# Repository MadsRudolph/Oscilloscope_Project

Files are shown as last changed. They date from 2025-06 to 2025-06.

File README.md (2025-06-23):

# ⚡ Oscilloscope & Signal Generator — DTU 30082 Project

Welcome to the **Oscilloscope_Project**, developed for the DTU course **30082 – Projektarbejde i Digitalteknik**.  
This full-stack embedded system connects a **Basys 2 FPGA** signal generator, an **ATmega2560 oscilloscope**, and a **LabVIEW GUI**.  
It visualizes analog signals in real time and allows waveform control through a robust UART/SPI interface.

📄 **[Project Report (PDF)](docs/Oscilloscope_Project_Rapport.pdf)**

---

## 📂 Project Structure

```
Oscilloscope_Project/
├── Microcontroller/           # PlatformIO-based ATmega2560 codebase
├── fpga/                      # VHDL projects for signal generation
├── docs/                      # Technical documentation and filter analysis
├── README.md
└── .gitignore
```

---

## 🎯 Project Goal

Design and implement a digital oscilloscope system that:
- Samples analog waveforms with an ATmega2560
- Sends sampled data to a LabVIEW GUI over UART
- Receives waveform control commands via UART (shape, freq, amp)
- Forwards these settings to an FPGA-based signal generator via SPI
- Generates analog output through PWM and active low-pass filtering

---

## 🧰 Technologies Used

| Platform | Tech | Purpose |
|---|---|---|
| ATmega2560 | C / PlatformIO | UART, ADC, SPI, Interrupts |
| FPGA (Basys 2) | VHDL (Xilinx ISE 14.7) | PWM waveform generation via SPI input |
| PC (Windows) | LabVIEW 2014 + NI-VISA | GUI and protocol management |
| Docs | KiCad / LTspice / Maple  | Active filter design + verification |

---

## 📡 Communication Protocols

### UART (MCU ↔ LabVIEW)
- **Baudrate:** `115200`, 8N1
- **Packet Format:**
  ```
  [0x55, 0xAA] + Length (2B) + Type (1B) + Data + Checksum (2B)
  ```
- **Types:**
  - `0x01` — Generator BTN pressed (with SW value)
  - `0x02` — Oscilloscope settings (sample rate, record length)
  - `0x03` — Start Bode plot
  - `0x04` — Trigger SPI stress test

### SPI (MCU → FPGA)
- 4-byte command packets:
  ```
  [0x55][ADDR][DATA][CHKSUM]
  ADDR: 1 = Amplitude, 2 = Frequency, 3 = Shape
  CHKSUM: ADDR ^ 0x55 ^ DATA
  ```

---

## 🔬 Subsystems

### 🟨 Microcontroller (ATmega2560)
- **ADC:** Timer1-triggered, 8-bit resolution (0–3.3V range)
- **UART0:** Debug output
- **UART1:** LabVIEW interface with interrupt-driven RX
- **SPI Master:** Sends waveform configuration to FPGA
- **Double/triple buffer** system for uninterrupted sampling
- **Stress test logic:** Transmits 10,000+ SPI packets after reset

### 🟦 FPGA (Basys 2)
- **PWM Generator:** Look-up tables drive pulse width per shape
- **SPI Slave:** Bit-shift protocol with byte-level sync and XOR validation
- **Waveform Types:** Constant, Square, Sawtooth, Triangle
- **Low-pass filter:** External 2nd–4th order analog smoothing stage

### 🟥 LabVIEW GUI
- **Tabs:** Generator, Oscilloscope, Bode Plot
- **Live Display:** ADC waveform and waveform config feedback
- **User Input:** Shape, amplitude, frequency, sample rate, record length
- **Checksums:** Supports ZERO16, LRC8, CRC16-CCITT
- **Simulator:** Emulate communication without hardware

---

## 🔍 Filter Design

- Designed using **KiCad** and validated in **LTspice**
- Active filters reduce PWM ripple for sine/sawtooth fidelity
- Mathematical modeling and transfer function analysis via **Maple**

### 📈 Output vs Filtered Waveform

The following scope capture shows both the raw PWM signal (red) and the filtered analog output (blue), confirming the effectiveness of the low-pass filter design:

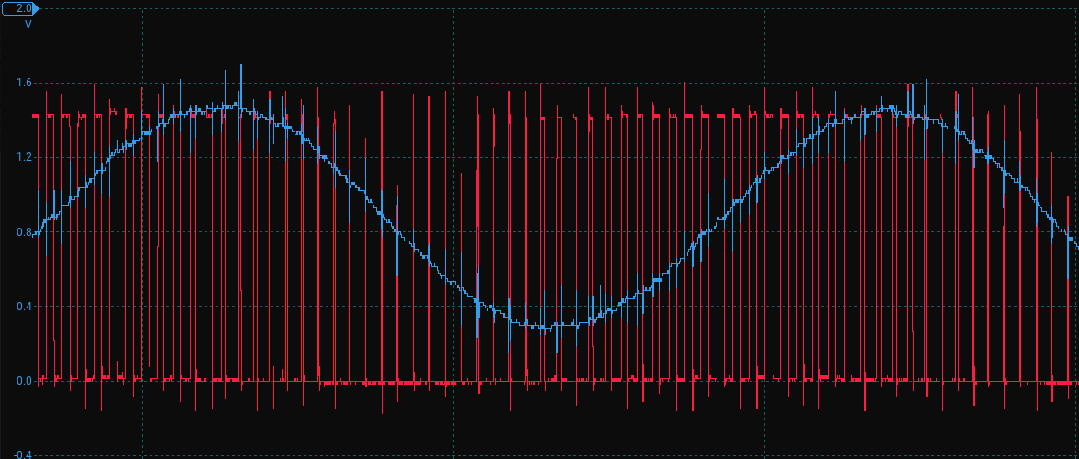
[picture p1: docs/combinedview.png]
Filtered PWM Output


---

## ⚠️ Known Limitations

- ❌ **User cannot freely adjust sample rate**  
  Sample rate is internally derived based on selected record length for optimal performance and continuous sampling.  
  Manual control of the sample rate is not supported in the final version, though it was implemented in earlier iterations.
  
- ✅ **Triangle waveform added**  
  Not part of original spec, added as an extra signal type.

---

## ✅ Features Implemented

- [x] Timer-driven ADC sampling (up to 10,000 sps)
- [x] UART parser with sync header, length, type, and checksum
- [x] SPI communication with custom byte-protocol and integrity checks
- [x] Real-time waveform generation: Constant, Square, Sawtooth, Triangle
- [x] GUI feedback and control via LabVIEW
- [x] External analog filtering tuned to PWM frequency
- [x] SPI stress test system (10k packets + FPGA reset)
- [x] Robust double-buffer system for uninterrupted signal capture

---

## 👥 Authors

**Embedded C (MCU, UART, SPI, ADC):**  
- Mads Rudolph  
- Sigurd Hestbech Christiansen  

**FPGA Design (PWM, LUTs, SPI Slave):**  
- Jonas Jensen  
- Andreas Jacobsen  
- Joakim Butenko

> All members contributed to testing, integration, and review across subsystems.

---

## 🔐 License

This project was created for the **DTU 30082 course** and is released for **educational, non-commercial use only**.

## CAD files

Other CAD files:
fpga/SPI_Test/isim/ProtokolBlok_isim_beh.exe.sim/work/ProtokolBlok_isim_beh.exe_main.nt64.obj
fpga/SPI_Test/isim/TB_TOP34444_isim_beh.exe.sim/work/TB_TOP34444_isim_beh.exe_main.nt64.obj
fpga/SignalGenerator/isim/FULL_BENCH_isim_beh.exe.sim/work/FULL_BENCH_isim_beh.exe_main.nt64.obj
fpga/SignalGenerator/isim/FULL_BENCH_isim_beh.exe.sim/work/a_3343343606_3212880686.nt64.obj
fpga/SignalGenerator/isim/FULL_BENCH_isim_beh.exe.sim/xilinxcorelib/a_2347390556_0543512595.nt64.obj
fpga/SignalGenerator/isim/precompiled.exe.sim/ieee/p_3564397177.nt64.obj
fpga/SignalGenerator/isim/precompiled.exe.sim/std/textio.nt64.obj
fpga/SPI_Test/isim/TB_TOP34444_isim_beh.exe.sim/work/a_4002409220_3212880686.nt64.obj
fpga/SignalGenerator/isim/FULL_BENCH_isim_beh.exe.sim/work/a_3580701064_3212880686.nt64.obj
fpga/SignalGenerator/isim/FULL_BENCH_isim_beh.exe.sim/xilinxcorelib/a_1380994670_2959432447.nt64.obj
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

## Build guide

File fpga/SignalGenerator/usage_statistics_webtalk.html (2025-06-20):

### Device Usage Page (usage_statistics_webtalk.html)

This HTML page displays the device usage statistics that will be sent to Xilinx.

Software Version and Target Device
Product Version: | ISE:14.7 (WebPack) - P.20131013 | Target Family: | Spartan3E
OS Platform: | LIN64 | Target Device: | xc3s100e
Project ID (random number) | 11f8526fd8dd4719a3ffcc0951b1ec72.9B5E89CDEDDC4133BDF7DFD157F22D5D.78 | Target Package: | cp132
Registration ID | 213343244_0_0_270 | Target Speed: | -4
Date Generated | 2025-06-20T10:25:10 | Tool Flow | ISE

User Environment
OS Name | Ubuntu | OS Release | Ubuntu 24.04.1 LTS
CPU Name | AMD Ryzen 7 7435HS | CPU Speed | 3094.104 MHz

Device Usage Statistics
Macro Statistics | Miscellaneous Statistics | Net Statistics | Site Usage

Accumulators=1

12-bit up accumulator=1

Adders/Subtractors=8

16-bit adder=7

9-bit adder=1

Comparators=5

12-bit comparator less=1

16-bit comparator greater=1

16-bit comparator less=1

7-bit comparator lessequal=1

8-bit comparator equal=1

Counters=5

12-bit up counter=2

16-bit up counter=1

2-bit up counter=1

25-bit up counter=1

Decoders=1

1-of-4 decoder=1

FSMs=3 Latches=2

20-bit latch=1

8-bit latch=1

Multiplexers=3

1-bit 4-to-1 multiplexer=1

4-bit 4-to-1 multiplexer=1

8-bit 5-to-1 multiplexer=1

ROMs=1

16x16-bit ROM=1

Registers=77

Flip-Flops=77

Xors=8

1-bit xor2=8

MiscellaneousStatistics

AGG_BONDED_IO=23

AGG_IO=23

AGG_SLICE=235

NUM_4_INPUT_LUT=378

NUM_BONDED_IBUF=6

NUM_BONDED_IOB=17

NUM_BUFGMUX=2

NUM_CYMUX=172

NUM_IOB_FF=1

NUM_LUT_RT=63

NUM_RAMB16=2

NUM_SLICEL=235

NUM_SLICE_FF=165

NUM_SLICE_LATCH=19

NUM_XOR=140

Xilinx Core blk_mem_gen_v7_1, Xilinx CORE Generator 14.1=1

NetStatistics

NumNets_Active=500

NumNets_Gnd=1

NumNets_Vcc=1

NumNodesOfType_Active_BRAMADDR=24

NumNodesOfType_Active_BRAMDUMMY=8

NumNodesOfType_Active_CLKPIN=107

NumNodesOfType_Active_CNTRLPIN=133

NumNodesOfType_Active_DOUBLE=758

NumNodesOfType_Active_DUMMY=1018

NumNodesOfType_Active_DUMMYBANK=28

NumNodesOfType_Active_DUMMYESC=6

NumNodesOfType_Active_GLOBAL=39

NumNodesOfType_Active_HFULLHEX=14

NumNodesOfType_Active_HLONG=1

NumNodesOfType_Active_HUNIHEX=38

NumNodesOfType_Active_INPUT=1228

NumNodesOfType_Active_IOBOUTPUT=6

NumNodesOfType_Active_OMUX=457

NumNodesOfType_Active_OUTPUT=466

NumNodesOfType_Active_PREBXBY=305

NumNodesOfType_Active_VFULLHEX=28

NumNodesOfType_Active_VLONG=10

NumNodesOfType_Active_VUNIHEX=37

NumNodesOfType_Vcc_BRAMDUMMY=2

NumNodesOfType_Vcc_CNTRLPIN=2

NumNodesOfType_Vcc_INPUT=7

NumNodesOfType_Vcc_PREBXBY=4

NumNodesOfType_Vcc_VCCOUT=8

SiteStatistics

IBUF-DIFFM=3

IBUF-DIFFMI=1

IBUF-IOB=1

IOB-DIFFM=7

IOB-DIFFS=8

SLICEL-SLICEM=96

SiteSummary

BUFGMUX=2

BUFGMUX_GCLKMUX=2

BUFGMUX_GCLK_BUFFER=2

IBUF=6

IBUF_INBUF=6

IBUF_PAD=6

IOB=17

IOB_OFF1=1

IOB_OUTBUF=17

IOB_PAD=17

RAMB16=2

RAMB16_RAMB16=2

RAMB16_RAMB16A=2

RAMB16_RAMB16B=2

SLICEL=235

SLICEL_C1VDD=3

SLICEL_C2VDD=11

SLICEL_CYMUXF=89

SLICEL_CYMUXG=83

SLICEL_F=201

SLICEL_F5MUX=19

SLICEL_FFX=95

SLICEL_FFY=89

SLICEL_G=177

SLICEL_GNDF=51

SLICEL_GNDG=38

SLICEL_XORF=71

SLICEL_XORG=69

Configuration Data

BUFGMUX

S=[S_INV:2] [S:0]

BUFGMUX_GCLKMUX

DISABLE_ATTR=[LOW:2]

S=[S_INV:2] [S:0]

IBUF

ICLK1=[ICLK1_INV:0] [ICLK1:1]

SR=[SR:1] [SR_INV:0]

IBUF_IFF1

CK=[CK:1] [CK_INV:0]

IFF1_INIT_ATTR=[INIT0:1]

IFF1_SR_ATTR=[SRLOW:1]

IFFATTRBOX=[ASYNC:1]

LATCH_OR_FF=[FF:1]

SR=[SR:1] [SR_INV:0]

IBUF_INBUF

IFD_DELAY_VALUE=[DLY2:1]

IBUF_PAD

IOATTRBOX=[LVCMOS25:6]

IOB

O1=[O1_INV:1] [O1:16]

OTCLK1=[OTCLK1_INV:0] [OTCLK1:1]

SR=[SR:1] [SR_INV:0]

IOB_OFF1

CK=[CK:1] [CK_INV:0]

D=[D:1] [D_INV:0]

LATCH_OR_FF=[FF:1]

OFF1_INIT_ATTR=[INIT0:1]

OFF1_SR_ATTR=[SRLOW:1]

OFFATTRBOX=[ASYNC:1]

SR=[SR:1] [SR_INV:0]

IOB_OUTBUF

IN=[IN_INV:1] [IN:16]

IOB_PAD

DRIVEATTRBOX=[12:17]

IOATTRBOX=[LVCMOS25:17]

SLEW=[SLOW:17]

RAMB16

CLKA=[CLKA_INV:0] [CLKA:2]

CLKB=[CLKB_INV:0] [CLKB:2]

ENA=[ENA_INV:0] [ENA:2]

ENB=[ENB_INV:0] [ENB:2]

SSRA=[SSRA_INV:0] [SSRA:2]

SSRB=[SSRB_INV:0] [SSRB:2]

WEA=[WEA:2] [WEA_INV:0]

WEB=[WEB:2] [WEB_INV:0]

RAMB16_RAMB16A

CLKA=[CLKA_INV:0] [CLKA:2]

ENA=[ENA_INV:0] [ENA:2]

PORTA_ATTR=[4096X4:2]

SSRA=[SSRA_INV:0] [SSRA:2]

WEA=[WEA:2] [WEA_INV:0]

WRITEMODEA=[WRITE_FIRST:2]

RAMB16_RAMB16B

CLKB=[CLKB_INV:0] [CLKB:2]

ENB=[ENB_INV:0] [ENB:2]

PORTB_ATTR=[4096X4:2]

SSRB=[SSRB_INV:0] [SSRB:2]

WEB=[WEB:2] [WEB_INV:0]

WRITEMODEB=[WRITE_FIRST:2]

SLICEL

BX=[BX_INV:0] [BX:64]

BY=[BY:33] [BY_INV:2]

CE=[CE:41] [CE_INV:0]

CIN=[CIN_INV:0] [CIN:80]

CLK=[CLK:92] [CLK_INV:12]

SR=[SR:91] [SR_INV:0]

SLICEL_CYMUXF

0=[0:89] [0_INV:0]

1=[1_INV:0] [1:89]

SLICEL_CYMUXG

0=[0:83] [0_INV:0]

SLICEL_F5MUX

S0=[S0:19] [S0_INV:0]

SLICEL_FFX

CE=[CE:36] [CE_INV:0]

CK=[CK:84] [CK_INV:11]

D=[D:95] [D_INV:0]

FFX_INIT_ATTR=[INIT0:95]

FFX_SR_ATTR=[SRLOW:95]

LATCH_OR_FF=[FF:84] [LATCH:11]

SR=[SR:84] [SR_INV:0]

SYNC_ATTR=[ASYNC:95]

SLICEL_FFY

CE=[CE:41] [CE_INV:0]

CK=[CK:81] [CK_INV:8]

D=[D:87] [D_INV:2]

FFY_INIT_ATTR=[INIT0:88] [INIT1:1]

FFY_SR_ATTR=[SRLOW:87] [SRHIGH:2]

LATCH_OR_FF=[FF:81] [LATCH:8]

SR=[SR:80] [SR_INV:0]

SYNC_ATTR=[ASYNC:89]

SLICEL_XORF

1=[1_INV:0] [1:71]

Pin Data

BUFGMUX

I0=2

O=2

S=2

BUFGMUX_GCLKMUX

I0=2

OUT=2

S=2

BUFGMUX_GCLK_BUFFER

IN=2

OUT=2

IBUF

I=6

PAD=6

IBUF_IFD_DELAY

IN=1

OUT=1

IBUF_IFF1

CK=1

D=1

Q=1

SR=1

IBUF_INBUF

IN=6

OUT=6

IBUF_PAD

PAD=6

IOB

O1=17

OTCLK1=1

PAD=17

SR=1

IOB_OFF1

CK=1

D=1

Q=1

SR=1

IOB_OUTBUF

IN=17

OUT=17

IOB_PAD

PAD=17

RAMB16

ADDRA10=2

ADDRA11=2

ADDRA12=2

ADDRA13=2

ADDRA2=2

ADDRA3=2

ADDRA4=2

ADDRA5=2

ADDRA6=2

ADDRA7=2

ADDRA8=2

ADDRA9=2

ADDRB10=2

ADDRB11=2

ADDRB12=2

ADDRB13=2

ADDRB2=2

ADDRB3=2

ADDRB4=2

ADDRB5=2

ADDRB6=2

ADDRB7=2

ADDRB8=2

ADDRB9=2

CLKA=2

CLKB=2

DIB0=2

DIB1=2

DIB2=2

DIB3=2

DOA0=2

DOA1=2

DOA2=2

DOA3=2

ENA=2

ENB=2

SSRA=2

SSRB=2

WEA=2

WEB=2

RAMB16_RAMB16

ADDRA=2

ADDRB=2

DIA=2

DIB=2

DOA=2

DOB=2

RAMB16_RAMB16A

ADDRA=2

ADDRA10=2

ADDRA11=2

ADDRA12=2

ADDRA13=2

ADDRA2=2

ADDRA3=2

ADDRA4=2

ADDRA5=2

ADDRA6=2

ADDRA7=2

ADDRA8=2

ADDRA9=2

CLKA=2

DIA=2

DOA=2

DOA0=2

DOA1=2

DOA2=2

DOA3=2

ENA=2

SSRA=2

WEA=2

RAMB16_RAMB16B

ADDRB=2

ADDRB10=2

ADDRB11=2

ADDRB12=2

ADDRB13=2

ADDRB2=2

ADDRB3=2

ADDRB4=2

ADDRB5=2

ADDRB6=2

ADDRB7=2

ADDRB8=2

ADDRB9=2

CLKB=2

DIB=2

DIB0=2

DIB1=2

DIB2=2

DIB3=2

DOB=2

ENB=2

SSRB=2

WEB=2

SLICEL

BX=64

BY=35

CE=41

CIN=80

CLK=104

COUT=83

F1=195

F2=158

F3=105

F4=74

G1=177

G2=142

G3=100

G4=63

SR=91

X=106

XB=2

XQ=95

Y=86

YQ=89

SLICEL_C1VDD

1=3

SLICEL_C2VDD

1=11

SLICEL_CYMUXF

0=89

1=89

OUT=89

S0=89

SLICEL_CYMUXG

0=83

1=83

OUT=83

S0=83

SLICEL_F

A1=195

A2=158

A3=105

A4=74

D=201

SLICEL_F5MUX

F=19

G=19

OUT=19

S0=19

SLICEL_FAND

0=5

1=5

O=5

SLICEL_FFX

CE=36

CK=95

D=95

Q=95

SR=84

SLICEL_FFY

CE=41

CK=89

D=89

Q=89

SR=80

SLICEL_G

A1=177

A2=142

A3=100

A4=63

D=177

SLICEL_GAND

0=9

1=9

O=9

SLICEL_GNDF

0=51

SLICEL_GNDG

0=38

SLICEL_VDDG

1=1

SLICEL_XORF

0=71

1=71

O=71

SLICEL_XORG

0=69

1=69

O=69

Tool Usage

Command Line History

xst -intstyle ise -ifn <ise_file>

xst -intstyle ise -ifn <ise_file>

xst -intstyle ise -ifn <ise_file>

xst -intstyle ise -ifn <ise_file>

xst -intstyle ise -ifn <ise_file>

xst -intstyle ise -ifn <ise_file>

xst -intstyle ise -ifn <ise_file>

xst -intstyle ise -ifn <ise_file>

xst -intstyle ise -ifn <ise_file>

xst -intstyle ise -ifn <ise_file>

xst -intstyle ise -ifn <ise_file>

xst -intstyle ise -ifn <ise_file>

ngdbuild -intstyle ise -dd _ngo -sd <dname> -nt timestamp -uc <ise_file> -p xc3s100e-cp132-4 <fname>.ngc <fname>.ngd

xst -intstyle ise -ifn <ise_file>

ngdbuild -intstyle ise -dd _ngo -sd <dname> -nt timestamp -uc <ise_file> -p xc3s100e-cp132-4 <fname>.ngc <fname>.ngd

xst -intstyle ise -ifn <ise_file>

xst -intstyle ise -ifn <ise_file>

xst -intstyle ise -ifn <ise_file>

xst -intstyle ise -ifn <ise_file>

xst -intstyle ise -ifn <ise_file>

ngdbuild -intstyle ise -dd _ngo -sd <dname> -nt timestamp -uc <ise_file> -p xc3s100e-cp132-4 <fname>.ngc <fname>.ngd

map -intstyle ise -p xc3s100e-cp132-4 -cm area -ir off -pr off -c 100 -o <fname>.ncd <fname>.ngd <fname>.pcf

par -w -intstyle ise -ol high -t 1 <fname>.ncd <fname>.ncd <fname>.pcf

trce -intstyle ise -v 3 -s 4 -n 3 -fastpaths -xml <fname>.twx <fname>.ncd -o <fname>.twr <fname>.pcf

bitgen -intstyle ise -f <fname>.ut <fname>.ncd

xst -intstyle ise -ifn <ise_file>

xst -intstyle ise -ifn <ise_file>

ngdbuild -intstyle ise -dd _ngo -sd <dname> -nt timestamp -uc <ise_file> -p xc3s100e-cp132-4 <fname>.ngc <fname>.ngd

map -intstyle ise -p xc3s100e-cp132-4 -cm area -ir off -pr off -c 100 -o <fname>.ncd <fname>.ngd <fname>.pcf

par -w -intstyle ise -ol high -t 1 <fname>.ncd <fname>.ncd <fname>.pcf

trce -intstyle ise -v 3 -s 4 -n 3 -fastpaths -xml <fname>.twx <fname>.ncd -o <fname>.twr <fname>.pcf

bitgen -intstyle ise -f <fname>.ut <fname>.ncd

xst -intstyle ise -ifn <ise_file>

ngdbuild -intstyle ise -dd _ngo -sd <dname> -nt timestamp -uc <ise_file> -p xc3s100e-cp132-4 <fname>.ngc <fname>.ngd

map -intstyle ise -p xc3s100e-cp132-4 -cm area -ir off -pr off -c 100 -o <fname>.ncd <fname>.ngd <fname>.pcf

par -w -intstyle ise -ol high -t 1 <fname>.ncd <fname>.ncd <fname>.pcf

trce -intstyle ise -v 3 -s 4 -n 3 -fastpaths -xml <fname>.twx <fname>.ncd -o <fname>.twr <fname>.pcf

bitgen -intstyle ise -f <fname>.ut <fname>.ncd

xst -intstyle ise -ifn <ise_file>

ngdbuild -intstyle ise -dd _ngo -sd <dname> -nt timestamp -uc <ise_file> -p xc3s100e-cp132-4 <fname>.ngc <fname>.ngd

map -intstyle ise -p xc3s100e-cp132-4 -cm area -ir off -pr off -c 100 -o <fname>.ncd <fname>.ngd <fname>.pcf

par -w -intstyle ise -ol high -t 1 <fname>.ncd <fname>.ncd <fname>.pcf

trce -intstyle ise -v 3 -s 4 -n 3 -fastpaths -xml <fname>.twx <fname>.ncd -o <fname>.twr <fname>.pcf

bitgen -intstyle ise -f <fname>.ut <fname>.ncd

xst -intstyle ise -ifn <ise_file>

xst -intstyle ise -ifn <ise_file>

xst -intstyle ise -ifn <ise_file>

ngdbuild -intstyle ise -dd _ngo -sd <dname> -nt timestamp -uc <ise_file> -p xc3s100e-cp132-4 <fname>.ngc <fname>.ngd

map -intstyle ise -p xc3s100e-cp132-4 -cm area -ir off -pr off -c 100 -o <fname>.ncd <fname>.ngd <fname>.pcf

par -w -intstyle ise -ol high -t 1 <fname>.ncd <fname>.ncd <fname>.pcf

trce -intstyle ise -v 3 -s 4 -n 3 -fastpaths -xml <fname>.twx <fname>.ncd -o <fname>.twr <fname>.pcf

bitgen -intstyle ise -f <fname>.ut <fname>.ncd

xst -intstyle ise -ifn <ise_file>

ngdbuild -intstyle ise -dd _ngo -sd <dname> -nt timestamp -uc <ise_file> -p xc3s100e-cp132-4 <fname>.ngc <fname>.ngd

map -intstyle ise -p xc3s100e-cp132-4 -cm area -ir off -pr off -c 100 -o <fname>.ncd <fname>.ngd <fname>.pcf

par -w -intstyle ise -ol high -t 1 <fname>.ncd <fname>.ncd <fname>.pcf

trce -intstyle ise -v 3 -s 4 -n 3 -fastpaths -xml <fname>.twx <fname>.ncd -o <fname>.twr <fname>.pcf

bitgen -intstyle ise -f <fname>.ut <fname>.ncd

xst -intstyle ise -ifn <ise_file>

xst -intstyle ise -ifn <ise_file>

xst -intstyle ise -ifn <ise_file>

ngdbuild -intstyle ise -dd _ngo -sd <dname> -nt timestamp -uc <ise_file> -p xc3s100e-cp132-4 <fname>.ngc <fname>.ngd

map -intstyle ise -p xc3s100e-cp132-4 -cm area -ir off -pr off -c 100 -o <fname>.ncd <fname>.ngd <fname>.pcf

par -w -intstyle ise -ol high -t 1 <fname>.ncd <fname>.ncd <fname>.pcf

trce -intstyle ise -v 3 -s 4 -n 3 -fastpaths -xml <fname>.twx <fname>.ncd -o <fname>.twr <fname>.pcf

bitgen -intstyle ise -f <fname>.ut <fname>.ncd

xst -intstyle ise -ifn <ise_file>

ngdbuild -intstyle ise -dd _ngo -sd <dname> -nt timestamp -uc <ise_file> -p xc3s100e-cp132-4 <fname>.ngc <fname>.ngd

map -intstyle ise -p xc3s100e-cp132-4 -cm area -ir off -pr off -c 100 -o <fname>.ncd <fname>.ngd <fname>.pcf

par -w -intstyle ise -ol high -t 1 <fname>.ncd <fname>.ncd <fname>.pcf

trce -intstyle ise -v 3 -s 4 -n 3 -fastpaths -xml <fname>.twx <fname>.ncd -o <fname>.twr <fname>.pcf

bitgen -intstyle ise -f <fname>.ut <fname>.ncd

xst -intstyle ise -ifn <ise_file>

ngdbuild -intstyle ise -dd _ngo -sd <dname> -nt timestamp -uc <ise_file> -p xc3s100e-cp132-4 <fname>.ngc <fname>.ngd

map -intstyle ise -p xc3s100e-cp132-4 -cm area -ir off -pr off -c 100 -o <fname>.ncd <fname>.ngd <fname>.pcf

par -w -intstyle ise -ol high -t 1 <fname>.ncd <fname>.ncd <fname>.pcf

trce -intstyle ise -v 3 -s 4 -n 3 -fastpaths -xml <fname>.twx <fname>.ncd -o <fname>.twr <fname>.pcf

bitgen -intstyle ise -f <fname>.ut <fname>.ncd

xst -intstyle ise -ifn <ise_file>

ngdbuild -intstyle ise -dd _ngo -sd <dname> -nt timestamp -uc <ise_file> -p xc3s100e-cp132-4 <fname>.ngc <fname>.ngd

ngdbuild -intstyle ise -dd _ngo -sd <dname> -nt timestamp -uc <ise_file> -p xc3s100e-cp132-4 <fname>.ngc <fname>.ngd

xst -intstyle ise -ifn <ise_file>

ngdbuild -intstyle ise -dd _ngo -sd <dname> -nt timestamp -uc <ise_file> -p xc3s100e-cp132-4 <fname>.ngc <fname>.ngd

xst -intstyle ise -ifn <ise_file>

ngdbuild -intstyle ise -dd _ngo -sd <dname> -nt timestamp -uc <ise_file> -p xc3s100e-cp132-4 <fname>.ngc <fname>.ngd

ngdbuild -intstyle ise -dd _ngo -sd <dname> -nt timestamp -uc <ise_file> -p xc3s100e-cp132-4 <fname>.ngc <fname>.ngd

xst -intstyle ise -ifn <ise_file>

ngdbuild -intstyle ise -dd _ngo -sd <dname> -nt timestamp -uc <ise_file> -p xc3s100e-cp132-4 <fname>.ngc <fname>.ngd

xst -intstyle ise -ifn <ise_file>

ngdbuild -intstyle ise -dd _ngo -sd <dname> -nt timestamp -uc <ise_file> -p xc3s100e-cp132-4 <fname>.ngc <fname>.ngd

map -intstyle ise -p xc3s100e-cp132-4 -cm area -ir off -pr off -c 100 -o <fname>.ncd <fname>.ngd <fname>.pcf

par -w -intstyle ise -ol high -t 1 <fname>.ncd <fname>.ncd <fname>.pcf

trce -intstyle ise -v 3 -s 4 -n 3 -fastpaths -xml <fname>.twx <fname>.ncd -o <fname>.twr <fname>.pcf

bitgen -intstyle ise -f <fname>.ut <fname>.ncd

xst -intstyle ise -ifn <ise_file>

ngdbuild -intstyle ise -dd _ngo -sd <dname> -nt timestamp -uc <ise_file> -p xc3s100e-cp132-4 <fname>.ngc <fname>.ngd

map -intstyle ise -p xc3s100e-cp132-4 -cm area -ir off -pr off -c 100 -o <fname>.ncd <fname>.ngd <fname>.pcf

par -w -intstyle ise -ol high -t 1 <fname>.ncd <fname>.ncd <fname>.pcf

trce -intstyle ise -v 3 -s 4 -n 3 -fastpaths -xml <fname>.twx <fname>.ncd -o <fname>.twr <fname>.pcf

bitgen -intstyle ise -f <fname>.ut <fname>.ncd

xst -intstyle ise -ifn <ise_file>

ngdbuild -intstyle ise -dd _ngo -sd <dname> -nt timestamp -uc <ise_file> -p xc3s100e-cp132-4 <fname>.ngc <fname>.ngd

map -intstyle ise -p xc3s100e-cp132-4 -cm area -ir off -pr off -c 100 -o <fname>.ncd <fname>.ngd <fname>.pcf

par -w -intstyle ise -ol high -t 1 <fname>.ncd <fname>.ncd <fname>.pcf

trce -intstyle ise -v 3 -s 4 -n 3 -fastpaths -xml <fname>.twx <fname>.ncd -o <fname>.twr <fname>.pcf

bitgen -intstyle ise -f <fname>.ut <fname>.ncd

xst -intstyle ise -ifn <ise_file>

xst -intstyle ise -ifn <ise_file>

xst -intstyle ise -ifn <ise_file>

ngdbuild -intstyle ise -dd _ngo -sd <dname> -nt timestamp -uc <ise_file> -p xc3s100e-cp132-4 <fname>.ngc <fname>.ngd

map -intstyle ise -p xc3s100e-cp132-4 -cm area -ir off -pr off -c 100 -o <fname>.ncd <fname>.ngd <fname>.pcf

par -w -intstyle ise -ol high -t 1 <fname>.ncd <fname>.ncd <fname>.pcf

trce -intstyle ise -v 3 -s 4 -n 3 -fastpaths -xml <fname>.twx <fname>.ncd -o <fname>.twr <fname>.pcf

bitgen -intstyle ise -f <fname>.ut <fname>.ncd

xst -intstyle ise -ifn <ise_file>

xst -intstyle ise -ifn <ise_file>

xst -intstyle ise -ifn <ise_file>

xst -intstyle ise -ifn <ise_file>

xst -intstyle ise -ifn <ise_file>

xst -intstyle ise -ifn <ise_file>

xst -intstyle ise -ifn <ise_file>

xst -intstyle ise -ifn <ise_file>

xst -intstyle ise -ifn <ise_file>

xst -intstyle ise -ifn <ise_file>

ngdbuild -intstyle ise -dd _ngo -sd <dname> -nt timestamp -uc <ise_file> -p xc3s100e-cp132-4 <fname>.ngc <fname>.ngd

map -intstyle ise -p xc3s100e-cp132-4 -cm area -ir off -pr off -c 100 -o <fname>.ncd <fname>.ngd <fname>.pcf

par -w -intstyle ise -ol high -t 1 <fname>.ncd <fname>.ncd <fname>.pcf

trce -intstyle ise -v 3 -s 4 -n 3 -fastpaths -xml <fname>.twx <fname>.ncd -o <fname>.twr <fname>.pcf

bitgen -intstyle ise -f <fname>.ut <fname>.ncd

xst -intstyle ise -ifn <ise_file>

xst -intstyle ise -ifn <ise_file>

xst -intstyle ise -ifn <ise_file>

xst -intstyle ise -ifn <ise_file>

xst -intstyle ise -ifn <ise_file>

xst -intstyle ise -ifn <ise_file>

ngdbuild -intstyle ise -dd _ngo -sd <dname> -nt timestamp -uc <ise_file> -p xc3s100e-cp132-4 <fname>.ngc <fname>.ngd

map -intstyle ise -p xc3s100e-cp132-4 -cm area -ir off -pr off -c 100 -o <fname>.ncd <fname>.ngd <fname>.pcf

par -w -intstyle ise -ol high -t 1 <fname>.ncd <fname>.ncd <fname>.pcf

trce -intstyle ise -v 3 -s 4 -n 3 -fastpaths -xml <fname>.twx <fname>.ncd -o <fname>.twr <fname>.pcf

bitgen -intstyle ise -f <fname>.ut <fname>.ncd

xst -intstyle ise -ifn <ise_file>

ngdbuild -intstyle ise -dd _ngo -sd <dname> -nt timestamp -uc <ise_file> -p xc3s100e-cp132-4 <fname>.ngc <fname>.ngd

map -intstyle ise -p xc3s100e-cp132-4 -cm area -ir off -pr off -c 100 -o <fname>.ncd <fname>.ngd <fname>.pcf

par -w -intstyle ise -ol high -t 1 <fname>.ncd <fname>.ncd <fname>.pcf

trce -intstyle ise -v 3 -s 4 -n 3 -fastpaths -xml <fname>.twx <fname>.ncd -o <fname>.twr <fname>.pcf

bitgen -intstyle ise -f <fname>.ut <fname>.ncd

xst -intstyle ise -ifn <ise_file>

ngdbuild -intstyle ise -dd _ngo -sd <dname> -nt timestamp -uc <ise_file> -p xc3s100e-cp132-4 <fname>.ngc <fname>.ngd

map -intstyle ise -p xc3s100e-cp132-4 -cm area -ir off -pr off -c 100 -o <fname>.ncd <fname>.ngd <fname>.pcf

par -w -intstyle ise -ol high -t 1 <fname>.ncd <fname>.ncd <fname>.pcf

trce -intstyle ise -v 3 -s 4 -n 3 -fastpaths -xml <fname>.twx <fname>.ncd -o <fname>.twr <fname>.pcf

bitgen -intstyle ise -f <fname>.ut <fname>.ncd

xst -intstyle ise -ifn <ise_file>

ngdbuild -intstyle ise -dd _ngo -sd <dname> -nt timestamp -uc <ise_file> -p xc3s100e-cp132-4 <fname>.ngc <fname>.ngd

map -intstyle ise -p xc3s100e-cp132-4 -cm area -ir off -pr off -c 100 -o <fname>.ncd <fname>.ngd <fname>.pcf

par -w -intstyle ise -ol high -t 1 <fname>.ncd <fname>.ncd <fname>.pcf

trce -intstyle ise -v 3 -s 4 -n 3 -fastpaths -xml <fname>.twx <fname>.ncd -o <fname>.twr <fname>.pcf

bitgen -intstyle ise -f <fname>.ut <fname>.ncd

xst -intstyle ise -ifn <ise_file>

ngdbuild -intstyle ise -dd _ngo -sd <dname> -nt timestamp -uc <ise_file> -p xc3s100e-cp132-4 <fname>.ngc <fname>.ngd

map -intstyle ise -p xc3s100e-cp132-4 -cm area -ir off -pr off -c 100 -o <fname>.ncd <fname>.ngd <fname>.pcf

par -w -intstyle ise -ol high -t 1 <fname>.ncd <fname>.ncd <fname>.pcf

trce -intstyle ise -v 3 -s 4 -n 3 -fastpaths -xml <fname>.twx <fname>.ncd -o <fname>.twr <fname>.pcf

bitgen -intstyle ise -f <fname>.ut <fname>.ncd

xst -intstyle ise -ifn <ise_file>

xst -intstyle ise -ifn <ise_file>

xst -intstyle ise -ifn <ise_file>

xst -intstyle ise -ifn <ise_file>

xst -intstyle ise -ifn <ise_file>

xst -intstyle ise -ifn <ise_file>

xst -intstyle ise -ifn <ise_file>

ngdbuild -intstyle ise -dd _ngo -sd <dname> -nt timestamp -uc <ise_file> -p xc3s100e-cp132-4 <fname>.ngc <fname>.ngd

map -intstyle ise -p xc3s100e-cp132-4 -cm area -ir off -pr off -c 100 -o <fname>.ncd <fname>.ngd <fname>.pcf

par -w -intstyle ise -ol high -t 1 <fname>.ncd <fname>.ncd <fname>.pcf

trce -intstyle ise -v 3 -s 4 -n 3 -fastpaths -xml <fname>.twx <fname>.ncd -o <fname>.twr <fname>.pcf

bitgen -intstyle ise -f <fname>.ut <fname>.ncd

xst -intstyle ise -ifn <ise_file>

xst -intstyle ise -ifn <ise_file>

ngdbuild -intstyle ise -dd _ngo -sd <dname> -nt timestamp -uc <ise_file> -p xc3s100e-cp132-4 <fname>.ngc <fname>.ngd

map -intstyle ise -p xc3s100e-cp132-4 -cm area -ir off -pr off -c 100 -o <fname>.ncd <fname>.ngd <fname>.pcf

par -w -intstyle ise -ol high -t 1 <fname>.ncd <fname>.ncd <fname>.pcf

trce -intstyle ise -v 3 -s 4 -n 3 -fastpaths -xml <fname>.twx <fname>.ncd -o <fname>.twr <fname>.pcf

bitgen -intstyle ise -f <fname>.ut <fname>.ncd

xst -intstyle ise -ifn <ise_file>

ngdbuild -intstyle ise -dd _ngo -sd <dname> -nt timestamp -uc <ise_file> -p xc3s100e-cp132-4 <fname>.ngc <fname>.ngd

map -intstyle ise -p xc3s100e-cp132-4 -cm area -ir off -pr off -c 100 -o <fname>.ncd <fname>.ngd <fname>.pcf

par -w -intstyle ise -ol high -t 1 <fname>.ncd <fname>.ncd <fname>.pcf

trce -intstyle ise -v 3 -s 4 -n 3 -fastpaths -xml <fname>.twx <fname>.ncd -o <fname>.twr <fname>.pcf

bitgen -intstyle ise -f <fname>.ut <fname>.ncd

xst -intstyle ise -ifn <ise_file>

xst -intstyle ise -ifn <ise_file>

ngdbuild -intstyle ise -dd _ngo -sd <dname> -nt timestamp -uc <ise_file> -p xc3s100e-cp132-4 <fname>.ngc <fname>.ngd

map -intstyle ise -p xc3s100e-cp132-4 -cm area -ir off -pr off -c 100 -o <fname>.ncd <fname>.ngd <fname>.pcf

par -w -intstyle ise -ol high -t 1 <fname>.ncd <fname>.ncd <fname>.pcf

trce -intstyle ise -v 3 -s 4 -n 3 -fastpaths -xml <fname>.twx <fname>.ncd -o <fname>.twr <fname>.pcf

bitgen -intstyle ise -f <fname>.ut <fname>.ncd

xst -intstyle ise -ifn <ise_file>

ngdbuild -intstyle ise -dd _ngo -sd <dname> -nt timestamp -uc <ise_file> -p xc3s100e-cp132-4 <fname>.ngc <fname>.ngd

map -intstyle ise -p xc3s100e-cp132-4 -cm area -ir off -pr off -c 100 -o <fname>.ncd <fname>.ngd <fname>.pcf

par -w -intstyle ise -ol high -t 1 <fname>.ncd <fname>.ncd <fname>.pcf

trce -intstyle ise -v 3 -s 4 -n 3 -fastpaths -xml <fname>.twx <fname>.ncd -o <fname>.twr <fname>.pcf

bitgen -intstyle ise -f <fname>.ut <fname>.ncd

xst -intstyle ise -ifn <ise_file>

ngdbuild -intstyle ise -dd _ngo -sd <dname> -nt timestamp -uc <ise_file> -p xc3s100e-cp132-4 <fname>.ngc <fname>.ngd

map -intstyle ise -p xc3s100e-cp132-4 -cm area -ir off -pr off -c 100 -o <fname>.ncd <fname>.ngd <fname>.pcf

par -w -intstyle ise -ol high -t 1 <fname>.ncd <fname>.ncd <fname>.pcf

trce -intstyle ise -v 3 -s 4 -n 3 -fastpaths -xml <fname>.twx <fname>.ncd -o <fname>.twr <fname>.pcf

bitgen -intstyle ise -f <fname>.ut <fname>.ncd

xst -intstyle ise -ifn <ise_file>

xst -intstyle ise -ifn <ise_file>

ngdbuild -intstyle ise -dd _ngo -sd <dname> -nt timestamp -uc <ise_file> -p xc3s100e-cp132-4 <fname>.ngc <fname>.ngd

map -intstyle ise -p xc3s100e-cp132-4 -cm area -ir off -pr off -c 100 -o <fname>.ncd <fname>.ngd <fname>.pcf

par -w -intstyle ise -ol high -t 1 <fname>.ncd <fname>.ncd <fname>.pcf

trce -intstyle ise -v 3 -s 4 -n 3 -fastpaths -xml <fname>.twx <fname>.ncd -o <fname>.twr <fname>.pcf

bitgen -intstyle ise -f <fname>.ut <fname>.ncd

xst -intstyle ise -ifn <ise_file>

ngdbuild -intstyle ise -dd _ngo -sd <dname> -nt timestamp -uc <ise_file> -p xc3s100e-cp132-4 <fname>.ngc <fname>.ngd

map -intstyle ise -p xc3s100e-cp132-4 -cm area -ir off -pr off -c 100 -o <fname>.ncd <fname>.ngd <fname>.pcf

par -w -intstyle ise -ol high -t 1 <fname>.ncd <fname>.ncd <fname>.pcf

trce -intstyle ise -v 3 -s 4 -n 3 -fastpaths -xml <fname>.twx <fname>.ncd -o <fname>.twr <fname>.pcf

bitgen -intstyle ise -f <fname>.ut <fname>.ncd

xst -intstyle ise -ifn <ise_file>

ngdbuild -intstyle ise -dd _ngo -sd <dname> -nt timestamp -uc <ise_file> -p xc3s100e-cp132-4 <fname>.ngc <fname>.ngd

ngdbuild -intstyle ise -dd _ngo -sd <dname> -nt timestamp -uc <ise_file> -p xc3s100e-cp132-4 <fname>.ngc <fname>.ngd

map -intstyle ise -p xc3s100e-cp132-4 -cm area -ir off -pr off -c 100 -o <fname>.ncd <fname>.ngd <fname>.pcf

par -w -intstyle ise -ol high -t 1 <fname>.ncd <fname>.ncd <fname>.pcf

trce -intstyle ise -v 3 -s 4 -n 3 -fastpaths -xml <fname>.twx <fname>.ncd -o <fname>.twr <fname>.pcf

bitgen -intstyle ise -f <fname>.ut <fname>.ncd

xst -intstyle ise -ifn <ise_file>

xst -intstyle ise -ifn <ise_file>

ngdbuild -intstyle ise -dd _ngo -sd <dname> -nt timestamp -uc <ise_file> -p xc3s100e-cp132-4 <fname>.ngc <fname>.ngd

map -intstyle ise -p xc3s100e-cp132-4 -cm area -ir off -pr off -c 100 -o <fname>.ncd <fname>.ngd <fname>.pcf

par -w -intstyle ise -ol high -t 1 <fname>.ncd <fname>.ncd <fname>.pcf

trce -intstyle ise -v 3 -s 4 -n 3 -fastpaths -xml <fname>.twx <fname>.ncd -o <fname>.twr <fname>.pcf

bitgen -intstyle ise -f <fname>.ut <fname>.ncd

xst -intstyle ise -ifn <ise_file>

ngdbuild -intstyle ise -dd _ngo -sd <dname> -nt timestamp -uc <ise_file> -p xc3s100e-cp132-4 <fname>.ngc <fname>.ngd

map -intstyle ise -p xc3s100e-cp132-4 -cm area -ir off -pr off -c 100 -o <fname>.ncd <fname>.ngd <fname>.pcf

par -w -intstyle ise -ol high -t 1 <fname>.ncd <fname>.ncd <fname>.pcf

trce -intstyle ise -v 3 -s 4 -n 3 -fastpaths -xml <fname>.twx <fname>.ncd -o <fname>.twr <fname>.pcf

bitgen -intstyle ise -f <fname>.ut <fname>.ncd

xst -intstyle ise -ifn <ise_file>

xst -intstyle ise -ifn <ise_file>

xst -intstyle ise -ifn <ise_file>

xst -intstyle ise -ifn <ise_file>

xst -intstyle ise -ifn <ise_file>

xst -intstyle ise -ifn <ise_file>

xst -intstyle ise -ifn <ise_file>

xst -intstyle ise -ifn <ise_file>

xst -intstyle ise -ifn <ise_file>

xst -intstyle ise -ifn <ise_file>

xst -intstyle ise -ifn <ise_file>

ngdbuild -intstyle ise -dd _ngo -sd <dname> -nt timestamp -uc <ise_file> -p xc3s100e-cp132-4 <fname>.ngc <fname>.ngd

map -intstyle ise -p xc3s100e-cp132-4 -cm area -ir off -pr off -c 100 -o <fname>.ncd <fname>.ngd <fname>.pcf

par -w -intstyle ise -ol high -t 1 <fname>.ncd <fname>.ncd <fname>.pcf

trce -intstyle ise -v 3 -s 4 -n 3 -fastpaths -xml <fname>.twx <fname>.ncd -o <fname>.twr <fname>.pcf

bitgen -intstyle ise -f <fname>.ut <fname>.ncd

xst -intstyle ise -ifn <ise_file>

xst -intstyle ise -ifn <ise_file>

ngdbuild -intstyle ise -dd _ngo -sd <dname> -nt timestamp -uc <ise_file> -p xc3s100e-cp132-4 <fname>.ngc <fname>.ngd

map -intstyle ise -p xc3s100e-cp132-4 -cm area -ir off -pr off -c 100 -o <fname>.ncd <fname>.ngd <fname>.pcf

par -w -intstyle ise -ol high -t 1 <fname>.ncd <fname>.ncd <fname>.pcf

trce -intstyle ise -v 3 -s 4 -n 3 -fastpaths -xml <fname>.twx <fname>.ncd -o <fname>.twr <fname>.pcf

bitgen -intstyle ise -f <fname>.ut <fname>.ncd

xst -intstyle ise -ifn <ise_file>

ngdbuild -intstyle ise -dd _ngo -sd <dname> -nt timestamp -uc <ise_file> -p xc3s100e-cp132-4 <fname>.ngc <fname>.ngd

map -intstyle ise -p xc3s100e-cp132-4 -cm area -ir off -pr off -c 100 -o <fname>.ncd <fname>.ngd <fname>.pcf

par -w -intstyle ise -ol high -t 1 <fname>.ncd <fname>.ncd <fname>.pcf

trce -intstyle ise -v 3 -s 4 -n 3 -fastpaths -xml <fname>.twx <fname>.ncd -o <fname>.twr <fname>.pcf

bitgen -intstyle ise -f <fname>.ut <fname>.ncd

xst -intstyle ise -ifn <ise_file>

ngdbuild -intstyle ise -dd _ngo -sd <dname> -nt timestamp -uc <ise_file> -p xc3s100e-cp132-4 <fname>.ngc <fname>.ngd

map -intstyle ise -p xc3s100e-cp132-4 -cm area -ir off -pr off -c 100 -o <fname>.ncd <fname>.ngd <fname>.pcf

par -w -intstyle ise -ol high -t 1 <fname>.ncd <fname>.ncd <fname>.pcf

trce -intstyle ise -v 3 -s 4 -n 3 -fastpaths -xml <fname>.twx <fname>.ncd -o <fname>.twr <fname>.pcf

bitgen -intstyle ise -f <fname>.ut <fname>.ncd

xst -intstyle ise -ifn <ise_file>

ngdbuild -intstyle ise -dd _ngo -sd <dname> -nt timestamp -uc <ise_file> -p xc3s100e-cp132-4 <fname>.ngc <fname>.ngd

map -intstyle ise -p xc3s100e-cp132-4 -cm area -ir off -pr off -c 100 -o <fname>.ncd <fname>.ngd <fname>.pcf

par -w -intstyle ise -ol high -t 1 <fname>.ncd <fname>.ncd <fname>.pcf

trce -intstyle ise -v 3 -s 4 -n 3 -fastpaths -xml <fname>.twx <fname>.ncd -o <fname>.twr <fname>.pcf

bitgen -intstyle ise -f <fname>.ut <fname>.ncd

xst -intstyle ise -ifn <ise_file>

ngdbuild -intstyle ise -dd _ngo -sd <dname> -nt timestamp -uc <ise_file> -p xc3s100e-cp132-4 <fname>.ngc <fname>.ngd

map -intstyle ise -p xc3s100e-cp132-4 -cm area -ir off -pr off -c 100 -o <fname>.ncd <fname>.ngd <fname>.pcf

par -w -intstyle ise -ol high -t 1 <fname>.ncd <fname>.ncd <fname>.pcf

trce -intstyle ise -v 3 -s 4 -n 3 -fastpaths -xml <fname>.twx <fname>.ncd -o <fname>.twr <fname>.pcf

bitgen -intstyle ise -f <fname>.ut <fname>.ncd

xst -intstyle ise -ifn <ise_file>

ngdbuild -intstyle ise -dd _ngo -sd <dname> -nt timestamp -uc <ise_file> -p xc3s100e-cp132-4 <fname>.ngc <fname>.ngd

map -intstyle ise -p xc3s100e-cp132-4 -cm area -ir off -pr off -c 100 -o <fname>.ncd <fname>.ngd <fname>.pcf

par -w -intstyle ise -ol high -t 1 <fname>.ncd <fname>.ncd <fname>.pcf

trce -intstyle ise -v 3 -s 4 -n 3 -fastpaths -xml <fname>.twx <fname>.ncd -o <fname>.twr <fname>.pcf

bitgen -intstyle ise -f <fname>.ut <fname>.ncd

xst -intstyle ise -ifn <ise_file>

ngdbuild -intstyle ise -dd _ngo -sd <dname> -nt timestamp -uc <ise_file> -p xc3s100e-cp132-4 <fname>.ngc <fname>.ngd

map -intstyle ise -p xc3s100e-cp132-4 -cm area -ir off -pr off -c 100 -o <fname>.ncd <fname>.ngd <fname>.pcf

par -w -intstyle ise -ol high -t 1 <fname>.ncd <fname>.ncd <fname>.pcf

trce -intstyle ise -v 3 -s 4 -n 3 -fastpaths -xml <fname>.twx <fname>.ncd -o <fname>.twr <fname>.pcf

bitgen -intstyle ise -f <fname>.ut <fname>.ncd

xst -intstyle ise -ifn <ise_file>

ngdbuild -intstyle ise -dd _ngo -sd <dname> -nt timestamp -uc <ise_file> -p xc3s100e-cp132-4 <fname>.ngc <fname>.ngd

map -intstyle ise -p xc3s100e-cp132-4 -cm area -ir off -pr off -c 100 -o <fname>.ncd <fname>.ngd <fname>.pcf

par -w -intstyle ise -ol high -t 1 <fname>.ncd <fname>.ncd <fname>.pcf

trce -intstyle ise -v 3 -s 4 -n 3 -fastpaths -xml <fname>.twx <fname>.ncd -o <fname>.twr <fname>.pcf

bitgen -intstyle ise -f <fname>.ut <fname>.ncd

xst -intstyle ise -ifn <ise_file>

ngdbuild -intstyle ise -dd _ngo -sd <dname> -nt timestamp -uc <ise_file> -p xc3s100e-cp132-4 <fname>.ngc <fname>.ngd

map -intstyle ise -p xc3s100e-cp132-4 -cm area -ir off -pr off -c 100 -o <fname>.ncd <fname>.ngd <fname>.pcf

par -w -intstyle ise -ol high -t 1 <fname>.ncd <fname>.ncd <fname>.pcf

trce -intstyle ise -v 3 -s 4 -n 3 -fastpaths -xml <fname>.twx <fname>.ncd -o <fname>.twr <fname>.pcf

bitgen -intstyle ise -f <fname>.ut <fname>.ncd

xst -intstyle ise -ifn <ise_file>

ngdbuild -intstyle ise -dd _ngo -sd <dname> -nt timestamp -uc <ise_file> -p xc3s100e-cp132-4 <fname>.ngc <fname>.ngd

map -intstyle ise -p xc3s100e-cp132-4 -cm area -ir off -pr off -c 100 -o <fname>.ncd <fname>.ngd <fname>.pcf

par -w -intstyle ise -ol high -t 1 <fname>.ncd <fname>.ncd <fname>.pcf

trce -intstyle ise -v 3 -s 4 -n 3 -fastpaths -xml <fname>.twx <fname>.ncd -o <fname>.twr <fname>.pcf

bitgen -intstyle ise -f <fname>.ut <fname>.ncd

xst -intstyle ise -ifn <ise_file>

ngdbuild -intstyle ise -dd _ngo -sd <dname> -nt timestamp -uc <ise_file> -p xc3s100e-cp132-4 <fname>.ngc <fname>.ngd

map -intstyle ise -p xc3s100e-cp132-4 -cm area -ir off -pr off -c 100 -o <fname>.ncd <fname>.ngd <fname>.pcf

par -w -intstyle ise -ol high -t 1 <fname>.ncd <fname>.ncd <fname>.pcf

trce -intstyle ise -v 3 -s 4 -n 3 -fastpaths -xml <fname>.twx <fname>.ncd -o <fname>.twr <fname>.pcf

bitgen -intstyle ise -f <fname>.ut <fname>.ncd

xst -intstyle ise -ifn <ise_file>

ngdbuild -intstyle ise -dd _ngo -sd <dname> -nt timestamp -uc <ise_file> -p xc3s100e-cp132-4 <fname>.ngc <fname>.ngd

map -intstyle ise -p xc3s100e-cp132-4 -cm area -ir off -pr off -c 100 -o <fname>.ncd <fname>.ngd <fname>.pcf

par -w -intstyle ise -ol high -t 1 <fname>.ncd <fname>.ncd <fname>.pcf

trce -intstyle ise -v 3 -s 4 -n 3 -fastpaths -xml <fname>.twx <fname>.ncd -o <fname>.twr <fname>.pcf

bitgen -intstyle ise -f <fname>.ut <fname>.ncd

xst -intstyle ise -ifn <ise_file>

ngdbuild -intstyle ise -dd _ngo -sd <dname> -nt timestamp -uc <ise_file> -p xc3s100e-cp132-4 <fname>.ngc <fname>.ngd

map -intstyle ise -p xc3s100e-cp132-4 -cm area -ir off -pr off -c 100 -o <fname>.ncd <fname>.ngd <fname>.pcf

par -w -intstyle ise -ol high -t 1 <fname>.ncd <fname>.ncd <fname>.pcf

trce -intstyle ise -v 3 -s 4 -n 3 -fastpaths -xml <fname>.twx <fname>.ncd -o <fname>.twr <fname>.pcf

bitgen -intstyle ise -f <fname>.ut <fname>.ncd

xst -intstyle ise -ifn <ise_file>

xst -intstyle ise -ifn <ise_file>

ngdbuild -intstyle ise -dd _ngo -sd <dname> -nt timestamp -uc <ise_file> -p xc3s100e-cp132-4 <fname>.ngc <fname>.ngd

map -intstyle ise -p xc3s100e-cp132-4 -cm area -ir off -pr off -c 100 -o <fname>.ncd <fname>.ngd <fname>.pcf

par -w -intstyle ise -ol high -t 1 <fname>.ncd <fname>.ncd <fname>.pcf

trce -intstyle ise -v 3 -s 4 -n 3 -fastpaths -xml <fname>.twx <fname>.ncd -o <fname>.twr <fname>.pcf

bitgen -intstyle ise -f <fname>.ut <fname>.ncd

xst -intstyle ise -ifn <ise_file>

ngdbuild -intstyle ise -dd _ngo -sd <dname> -nt timestamp -uc <ise_file> -p xc3s100e-cp132-4 <fname>.ngc <fname>.ngd

map -intstyle ise -p xc3s100e-cp132-4 -cm area -ir off -pr off -c 100 -o <fname>.ncd <fname>.ngd <fname>.pcf

par -w -intstyle ise -ol high -t 1 <fname>.ncd <fname>.ncd <fname>.pcf

trce -intstyle ise -v 3 -s 4 -n 3 -fastpaths -xml <fname>.twx <fname>.ncd -o <fname>.twr <fname>.pcf

bitgen -intstyle ise -f <fname>.ut <fname>.ncd

xst -intstyle ise -ifn <ise_file>

ngdbuild -intstyle ise -dd _ngo -sd <dname> -nt timestamp -uc <ise_file> -p xc3s100e-cp132-4 <fname>.ngc <fname>.ngd

map -intstyle ise -p xc3s100e-cp132-4 -cm area -ir off -pr off -c 100 -o <fname>.ncd <fname>.ngd <fname>.pcf

par -w -intstyle ise -ol high -t 1 <fname>.ncd <fname>.ncd <fname>.pcf

trce -intstyle ise -v 3 -s 4 -n 3 -fastpaths -xml <fname>.twx <fname>.ncd -o <fname>.twr <fname>.pcf

bitgen -intstyle ise -f <fname>.ut <fname>.ncd

xst -intstyle ise -ifn <ise_file>

ngdbuild -intstyle ise -dd _ngo -sd <dname> -nt timestamp -uc <ise_file> -p xc3s100e-cp132-4 <fname>.ngc <fname>.ngd

map -intstyle ise -p xc3s100e-cp132-4 -cm area -ir off -pr off -c 100 -o <fname>.ncd <fname>.ngd <fname>.pcf

par -w -intstyle ise -ol high -t 1 <fname>.ncd <fname>.ncd <fname>.pcf

trce -intstyle ise -v 3 -s 4 -n 3 -fastpaths -xml <fname>.twx <fname>.ncd -o <fname>.twr <fname>.pcf

bitgen -intstyle ise -f <fname>.ut <fname>.ncd

xst -intstyle ise -ifn <ise_file>

xst -intstyle ise -ifn <ise_file>

xst -intstyle ise -ifn <ise_file>

xst -intstyle ise -ifn <ise_file>

xst -intstyle ise -ifn <ise_file>

xst -intstyle ise -ifn <ise_file>

xst -intstyle ise -ifn <ise_file>

xst -intstyle ise -ifn <ise_file>

xst -intstyle ise -ifn <ise_file>

ngdbuild -intstyle ise -dd _ngo -sd <dname> -nt timestamp -uc <ise_file> -p xc3s100e-cp132-4 <fname>.ngc <fname>.ngd

map -intstyle ise -p xc3s100e-cp132-4 -cm area -ir off -pr off -c 100 -o <fname>.ncd <fname>.ngd <fname>.pcf

par -w -intstyle ise -ol high -t 1 <fname>.ncd <fname>.ncd <fname>.pcf

trce -intstyle ise -v 3 -s 4 -n 3 -fastpaths -xml <fname>.twx <fname>.ncd -o <fname>.twr <fname>.pcf

bitgen -intstyle ise -f <fname>.ut <fname>.ncd

xst -intstyle ise -ifn <ise_file>

ngdbuild -intstyle ise -dd _ngo -sd <dname> -nt timestamp -uc <ise_file> -p xc3s100e-cp132-4 <fname>.ngc <fname>.ngd

map -intstyle ise -p xc3s100e-cp132-4 -cm area -ir off -pr off -c 100 -o <fname>.ncd <fname>.ngd <fname>.pcf

par -w -intstyle ise -ol high -t 1 <fname>.ncd <fname>.ncd <fname>.pcf

trce -intstyle ise -v 3 -s 4 -n 3 -fastpaths -xml <fname>.twx <fname>.ncd -o <fname>.twr <fname>.pcf

bitgen -intstyle ise -f <fname>.ut <fname>.ncd

xst -intstyle ise -ifn <ise_file>

ngdbuild -intstyle ise -dd _ngo -sd <dname> -nt timestamp -uc <ise_file> -p xc3s100e-cp132-4 <fname>.ngc <fname>.ngd

map -intstyle ise -p xc3s100e-cp132-4 -cm area -ir off -pr off -c 100 -o <fname>.ncd <fname>.ngd <fname>.pcf

par -w -intstyle ise -ol high -t 1 <fname>.ncd <fname>.ncd <fname>.pcf

trce -intstyle ise -v 3 -s 4 -n 3 -fastpaths -xml <fname>.twx <fname>.ncd -o <fname>.twr <fname>.pcf

bitgen -intstyle ise -f <fname>.ut <fname>.ncd

xst -intstyle ise -ifn <ise_file>

ngdbuild -intstyle ise -dd _ngo -sd <dname> -nt timestamp -uc <ise_file> -p xc3s100e-cp132-4 <fname>.ngc <fname>.ngd

map -intstyle ise -p xc3s100e-cp132-4 -cm area -ir off -pr off -c 100 -o <fname>.ncd <fname>.ngd <fname>.pcf

par -w -intstyle ise -ol high -t 1 <fname>.ncd <fname>.ncd <fname>.pcf

trce -intstyle ise -v 3 -s 4 -n 3 -fastpaths -xml <fname>.twx <fname>.ncd -o <fname>.twr <fname>.pcf

bitgen -intstyle ise -f <fname>.ut <fname>.ncd

xst -intstyle ise -ifn <ise_file>

xst -intstyle ise -ifn <ise_file>

ngdbuild -intstyle ise -dd _ngo -sd <dname> -nt timestamp -uc <ise_file> -p xc3s100e-cp132-4 <fname>.ngc <fname>.ngd

map -intstyle ise -p xc3s100e-cp132-4 -cm area -ir off -pr off -c 100 -o <fname>.ncd <fname>.ngd <fname>.pcf

par -w -intstyle ise -ol high -t 1 <fname>.ncd <fname>.ncd <fname>.pcf

trce -intstyle ise -v 3 -s 4 -n 3 -fastpaths -xml <fname>.twx <fname>.ncd -o <fname>.twr <fname>.pcf

bitgen -intstyle ise -f <fname>.ut <fname>.ncd

xst -intstyle ise -ifn <ise_file>

ngdbuild -intstyle ise -dd _ngo -sd <dname> -nt timestamp -uc <ise_file> -p xc3s100e-cp132-4 <fname>.ngc <fname>.ngd

map -intstyle ise -p xc3s100e-cp132-4 -cm area -ir off -pr off -c 100 -o <fname>.ncd <fname>.ngd <fname>.pcf

par -w -intstyle ise -ol high -t 1 <fname>.ncd <fname>.ncd <fname>.pcf

trce -intstyle ise -v 3 -s 4 -n 3 -fastpaths -xml <fname>.twx <fname>.ncd -o <fname>.twr <fname>.pcf

bitgen -intstyle ise -f <fname>.ut <fname>.ncd

xst -intstyle ise -ifn <ise_file>

ngdbuild -intstyle ise -dd _ngo -sd <dname> -nt timestamp -uc <ise_file> -p xc3s100e-cp132-4 <fname>.ngc <fname>.ngd

map -intstyle ise -p xc3s100e-cp132-4 -cm area -ir off -pr off -c 100 -o <fname>.ncd <fname>.ngd <fname>.pcf

par -w -intstyle ise -ol high -t 1 <fname>.ncd <fname>.ncd <fname>.pcf

trce -intstyle ise -v 3 -s 4 -n 3 -fastpaths -xml <fname>.twx <fname>.ncd -o <fname>.twr <fname>.pcf

bitgen -intstyle ise -f <fname>.ut <fname>.ncd

xst -intstyle ise -ifn <ise_file>

ngdbuild -intstyle ise -dd _ngo -sd <dname> -nt timestamp -uc <ise_file> -p xc3s100e-cp132-4 <fname>.ngc <fname>.ngd

map -intstyle ise -p xc3s100e-cp132-4 -cm area -ir off -pr off -c 100 -o <fname>.ncd <fname>.ngd <fname>.pcf

par -w -intstyle ise -ol high -t 1 <fname>.ncd <fname>.ncd <fname>.pcf

trce -intstyle ise -v 3 -s 4 -n 3 -fastpaths -xml <fname>.twx <fname>.ncd -o <fname>.twr <fname>.pcf

bitgen -intstyle ise -f <fname>.ut <fname>.ncd

xst -intstyle ise -ifn <ise_file>

ngdbuild -intstyle ise -dd _ngo -sd <dname> -nt timestamp -uc <ise_file> -p xc3s100e-cp132-4 <fname>.ngc <fname>.ngd

map -intstyle ise -p xc3s100e-cp132-4 -cm area -ir off -pr off -c 100 -o <fname>.ncd <fname>.ngd <fname>.pcf

par -w -intstyle ise -ol high -t 1 <fname>.ncd <fname>.ncd <fname>.pcf

trce -intstyle ise -v 3 -s 4 -n 3 -fastpaths -xml <fname>.twx <fname>.ncd -o <fname>.twr <fname>.pcf

bitgen -intstyle ise -f <fname>.ut <fname>.ncd

xst -intstyle ise -ifn <ise_file>

ngdbuild -intstyle ise -dd _ngo -sd <dname> -nt timestamp -uc <ise_file> -p xc3s100e-cp132-4 <fname>.ngc <fname>.ngd

map -intstyle ise -p xc3s100e-cp132-4 -cm area -ir off -pr off -c 100 -o <fname>.ncd <fname>.ngd <fname>.pcf

par -w -intstyle ise -ol high -t 1 <fname>.ncd <fname>.ncd <fname>.pcf

trce -intstyle ise -v 3 -s 4 -n 3 -fastpaths -xml <fname>.twx <fname>.ncd -o <fname>.twr <fname>.pcf

bitgen -intstyle ise -f <fname>.ut <fname>.ncd

xst -intstyle ise -ifn <ise_file>

ngdbuild -intstyle ise -dd _ngo -sd <dname> -nt timestamp -uc <ise_file> -p xc3s100e-cp132-4 <fname>.ngc <fname>.ngd

map -intstyle ise -p xc3s100e-cp132-4 -cm area -ir off -pr off -c 100 -o <fname>.ncd <fname>.ngd <fname>.pcf

par -w -intstyle ise -ol high -t 1 <fname>.ncd <fname>.ncd <fname>.pcf

trce -intstyle ise -v 3 -s 4 -n 3 -fastpaths -xml <fname>.twx <fname>.ncd -o <fname>.twr <fname>.pcf

bitgen -intstyle ise -f <fname>.ut <fname>.ncd

xst -intstyle ise -ifn <ise_file>

ngdbuild -intstyle ise -dd _ngo -sd <dname> -nt timestamp -uc <ise_file> -p xc3s100e-cp132-4 <fname>.ngc <fname>.ngd

map -intstyle ise -p xc3s100e-cp132-4 -cm area -ir off -pr off -c 100 -o <fname>.ncd <fname>.ngd <fname>.pcf

par -w -intstyle ise -ol high -t 1 <fname>.ncd <fname>.ncd <fname>.pcf

trce -intstyle ise -v 3 -s 4 -n 3 -fastpaths -xml <fname>.twx <fname>.ncd -o <fname>.twr <fname>.pcf

bitgen -intstyle ise -f <fname>.ut <fname>.ncd

xst -intstyle ise -ifn <ise_file>

ngdbuild -intstyle ise -dd _ngo -sd <dname> -nt timestamp -uc <ise_file> -p xc3s100e-cp132-4 <fname>.ngc <fname>.ngd

map -intstyle ise -p xc3s100e-cp132-4 -cm area -ir off -pr off -c 100 -o <fname>.ncd <fname>.ngd <fname>.pcf

par -w -intstyle ise -ol high -t 1 <fname>.ncd <fname>.ncd <fname>.pcf

trce -intstyle ise -v 3 -s 4 -n 3 -fastpaths -xml <fname>.twx <fname>.ncd -o <fname>.twr <fname>.pcf

bitgen -intstyle ise -f <fname>.ut <fname>.ncd

xst -intstyle ise -ifn <ise_file>

ngdbuild -intstyle ise -dd _ngo -sd <dname> -nt timestamp -uc <ise_file> -p xc3s100e-cp132-4 <fname>.ngc <fname>.ngd

map -intstyle ise -p xc3s100e-cp132-4 -cm area -ir off -pr off -c 100 -o <fname>.ncd <fname>.ngd <fname>.pcf

par -w -intstyle ise -ol high -t 1 <fname>.ncd <fname>.ncd <fname>.pcf

trce -intstyle ise -v 3 -s 4 -n 3 -fastpaths -xml <fname>.twx <fname>.ncd -o <fname>.twr <fname>.pcf

bitgen -intstyle ise -f <fname>.ut <fname>.ncd

xst -intstyle ise -ifn <ise_file>

xst -intstyle ise -ifn <ise_file>

xst -intstyle ise -ifn <ise_file>

xst -intstyle ise -ifn <ise_file>

xst -intstyle ise -ifn <ise_file>

xst -intstyle ise -ifn <ise_file>

ngdbuild -intstyle ise -dd _ngo -sd <dname> -nt timestamp -uc <ise_file> -p xc3s100e-cp132-4 <fname>.ngc <fname>.ngd

map -intstyle ise -p xc3s100e-cp132-4 -cm area -ir off -pr off -c 100 -o <fname>.ncd <fname>.ngd <fname>.pcf

par -w -intstyle ise -ol high -t 1 <fname>.ncd <fname>.ncd <fname>.pcf

trce -intstyle ise -v 3 -s 4 -n 3 -fastpaths -xml <fname>.twx <fname>.ncd -o <fname>.twr <fname>.pcf

bitgen -intstyle ise -f <fname>.ut <fname>.ncd

xst -intstyle ise -ifn <ise_file>

ngdbuild -intstyle ise -dd _ngo -sd <dname> -nt timestamp -uc <ise_file> -p xc3s100e-cp132-4 <fname>.ngc <fname>.ngd

map -intstyle ise -p xc3s100e-cp132-4 -cm area -ir off -pr off -c 100 -o <fname>.ncd <fname>.ngd <fname>.pcf

par -w -intstyle ise -ol high -t 1 <fname>.ncd <fname>.ncd <fname>.pcf

trce -intstyle ise -v 3 -s 4 -n 3 -fastpaths -xml <fname>.twx <fname>.ncd -o <fname>.twr <fname>.pcf

bitgen -intstyle ise -f <fname>.ut <fname>.ncd

xst -intstyle ise -ifn <ise_file>

ngdbuild -intstyle ise -dd _ngo -sd <dname> -nt timestamp -uc <ise_file> -p xc3s100e-cp132-4 <fname>.ngc <fname>.ngd

map -intstyle ise -p xc3s100e-cp132-4 -cm area -ir off -pr off -c 100 -o <fname>.ncd <fname>.ngd <fname>.pcf

par -w -intstyle ise -ol high -t 1 <fname>.ncd <fname>.ncd <fname>.pcf

trce -intstyle ise -v 3 -s 4 -n 3 -fastpaths -xml <fname>.twx <fname>.ncd -o <fname>.twr <fname>.pcf

bitgen -intstyle ise -f <fname>.ut <fname>.ncd

xst -intstyle ise -ifn <ise_file>

xst -intstyle ise -ifn <ise_file>

ngdbuild -intstyle ise -dd _ngo -sd <dname> -nt timestamp -uc <ise_file> -p xc3s100e-cp132-4 <fname>.ngc <fname>.ngd

map -intstyle ise -p xc3s100e-cp132-4 -cm area -ir off -pr off -c 100 -o <fname>.ncd <fname>.ngd <fname>.pcf

par -w -intstyle ise -ol high -t 1 <fname>.ncd <fname>.ncd <fname>.pcf

trce -intstyle ise -v 3 -s 4 -n 3 -fastpaths -xml <fname>.twx <fname>.ncd -o <fname>.twr <fname>.pcf

bitgen -intstyle ise -f <fname>.ut <fname>.ncd

xst -intstyle ise -ifn <ise_file>

xst -intstyle ise -ifn <ise_file>

xst -intstyle ise -ifn <ise_file>

xst -intstyle ise -ifn <ise_file>

ngdbuild -intstyle ise -dd _ngo -sd <dname> -nt timestamp -uc <ise_file> -p xc3s100e-cp132-4 <fname>.ngc <fname>.ngd

map -intstyle ise -p xc3s100e-cp132-4 -cm area -ir off -pr off -c 100 -o <fname>.ncd <fname>.ngd <fname>.pcf

par -w -intstyle ise -ol high -t 1 <fname>.ncd <fname>.ncd <fname>.pcf

trce -intstyle ise -v 3 -s 4 -n 3 -fastpaths -xml <fname>.twx <fname>.ncd -o <fname>.twr <fname>.pcf

bitgen -intstyle ise -f <fname>.ut <fname>.ncd

xst -intstyle ise -ifn <ise_file>

ngdbuild -intstyle ise -dd _ngo -sd <dname> -nt timestamp -uc <ise_file> -p xc3s100e-cp132-4 <fname>.ngc <fname>.ngd

map -intstyle ise -p xc3s100e-cp132-4 -cm area -ir off -pr off -c 100 -o <fname>.ncd <fname>.ngd <fname>.pcf

par -w -intstyle ise -ol high -t 1 <fname>.ncd <fname>.ncd <fname>.pcf

trce -intstyle ise -v 3 -s 4 -n 3 -fastpaths -xml <fname>.twx <fname>.ncd -o <fname>.twr <fname>.pcf

bitgen -intstyle ise -f <fname>.ut <fname>.ncd

xst -intstyle ise -ifn <ise_file>

xst -intstyle ise -ifn <ise_file>

ngdbuild -intstyle ise -dd _ngo -sd <dname> -nt timestamp -uc <ise_file> -p xc3s100e-cp132-4 <fname>.ngc <fname>.ngd

map -intstyle ise -p xc3s100e-cp132-4 -cm area -ir off -pr off -c 100 -o <fname>.ncd <fname>.ngd <fname>.pcf

par -w -intstyle ise -ol high -t 1 <fname>.ncd <fname>.ncd <fname>.pcf

trce -intstyle ise -v 3 -s 4 -n 3 -fastpaths -xml <fname>.twx <fname>.ncd -o <fname>.twr <fname>.pcf

bitgen -intstyle ise -f <fname>.ut <fname>.ncd

xst -intstyle ise -ifn <ise_file>

ngdbuild -intstyle ise -dd _ngo -sd <dname> -nt timestamp -uc <ise_file> -p xc3s100e-cp132-4 <fname>.ngc <fname>.ngd

map -intstyle ise -p xc3s100e-cp132-4 -cm area -ir off -pr off -c 100 -o <fname>.ncd <fname>.ngd <fname>.pcf

par -w -intstyle ise -ol high -t 1 <fname>.ncd <fname>.ncd <fname>.pcf

trce -intstyle ise -v 3 -s 4 -n 3 -fastpaths -xml <fname>.twx <fname>.ncd -o <fname>.twr <fname>.pcf

bitgen -intstyle ise -f <fname>.ut <fname>.ncd

fuse

Software Quality
Run Statistics
Program Name | Runs Started | Runs Finished | Errors | Fatal Errors | Internal Errors | Exceptions | Core Dumps
_impact | 1 | 1 | 0 | 0 | 0 | 0 | 0
bitgen | 6 | 6 | 0 | 0 | 0 | 0 | 0
map | 6 | 6 | 0 | 0 | 0 | 0 | 0
ngdbuild | 7 | 7 | 0 | 0 | 0 | 0 | 0
par | 6 | 6 | 0 | 0 | 0 | 0 | 0
trce | 6 | 6 | 0 | 0 | 0 | 0 | 0
xst | 14 | 14 | 0 | 0 | 0 | 0 | 0

Project Statistics
PROPEXT_xilxSynthMaxFanout_virtex2=100000 | PROP_Enable_Message_Filtering=false
PROP_FitterReportFormat=HTML | PROP_LastAppliedGoal=Balanced
PROP_LastAppliedStrategy=Xilinx Default (unlocked) | PROP_ManualCompileOrderImp=false
PROP_PropSpecInProjFile=Store all values | PROP_SelectedInstanceHierarchicalPath=/FULL_BENCH
PROP_Simulator=ISim (VHDL/Verilog) | PROP_SynthTopFile=changed
PROP_Top_Level_Module_Type=HDL | PROP_UseSmartGuide=false
PROP_UserConstraintEditorPreference=Text Editor | PROP_intProjectCreationTimestamp=2025-06-04T13:30:59
PROP_intWbtProjectID=9B5E89CDEDDC4133BDF7DFD157F22D5D | PROP_intWbtProjectIteration=78
PROP_intWorkingDirLocWRTProjDir=Same | PROP_intWorkingDirUsed=No
PROP_selectedSimRootSourceNode_behav=work.FULL_BENCH | PROP_xilxBitgStart_IntDone=true
PROP_AutoTop=true | PROP_DevFamily=Spartan3E
PROP_DevDevice=xc3s100e | PROP_DevFamilyPMName=spartan3e
PROP_DevPackage=cp132 | PROP_Synthesis_Tool=XST (VHDL/Verilog)
PROP_DevSpeed=-4 | PROP_PreferredLanguage=VHDL
FILE_COREGEN=1 | FILE_UCF=1
FILE_USERDOC=1 | FILE_VHDL=14

Core Statistics
Core Type=blk_mem_gen_v7_1
c_addra_width=12 | c_addrb_width=12 | c_algorithm=1 | c_axi_id_width=4
c_axi_slave_type=0 | c_axi_type=1 | c_byte_size=9 | c_common_clk=0
c_default_data=0 | c_disable_warn_bhv_coll=0 | c_disable_warn_bhv_range=0 | c_elaboration_dir=masked_value
c_enable_32bit_address=0 | c_family=spartan3 | c_has_axi_id=0 | c_has_ena=0
c_has_enb=0 | c_has_injecterr=0 | c_has_mem_output_regs_a=0 | c_has_mem_output_regs_b=0
c_has_mux_output_regs_a=0 | c_has_mux_output_regs_b=0 | c_has_regcea=0 | c_has_regceb=0
c_has_rsta=0 | c_has_rstb=0 | c_has_softecc_input_regs_a=0 | c_has_softecc_output_regs_b=0
c_init_file_name=fname.mif | c_inita_val=0 | c_initb_val=0 | c_interface_type=0
c_load_init_file=1 | c_mem_type=3 | c_mux_pipeline_stages=0 | c_prim_type=1
c_read_depth_a=4096 | c_read_depth_b=4096 | c_read_width_a=8 | c_read_width_b=8
c_rst_priority_a=CE | c_rst_priority_b=CE | c_rst_type=SYNC | c_rstram_a=0
c_rstram_b=0 | c_sim_collision_check=ALL | c_use_byte_wea=0 | c_use_byte_web=0
c_use_default_data=0 | c_use_ecc=0 | c_use_softecc=0 | c_wea_width=1
c_web_width=1 | c_write_depth_a=4096 | c_write_depth_b=4096 | c_write_mode_a=WRITE_FIRST
c_write_mode_b=WRITE_FIRST | c_write_width_a=8 | c_write_width_b=8 | c_xdevicefamily=spartan3e

Unisim Statistics
NGDBUILD_PRE_UNISIM_SUMMARY
NGDBUILD_NUM_BUFGP=2 | NGDBUILD_NUM_FDC=64 | NGDBUILD_NUM_FDCE=99 | NGDBUILD_NUM_FDE=1
NGDBUILD_NUM_FDP=1 | NGDBUILD_NUM_FDPE=1 | NGDBUILD_NUM_GND=2 | NGDBUILD_NUM_IBUF=4
NGDBUILD_NUM_INV=12 | NGDBUILD_NUM_LD=19 | NGDBUILD_NUM_LUT1=63 | NGDBUILD_NUM_LUT2=91
NGDBUILD_NUM_LUT2_D=1 | NGDBUILD_NUM_LUT2_L=1 | NGDBUILD_NUM_LUT3=62 | NGDBUILD_NUM_LUT3_D=1
NGDBUILD_NUM_LUT3_L=7 | NGDBUILD_NUM_LUT4=131 | NGDBUILD_NUM_LUT4_D=1 | NGDBUILD_NUM_LUT4_L=5
NGDBUILD_NUM_MUXCY=172 | NGDBUILD_NUM_MUXF5=19 | NGDBUILD_NUM_OBUF=17 | NGDBUILD_NUM_RAMB16_S4_S4=2
NGDBUILD_NUM_VCC=2 | NGDBUILD_NUM_XORCY=140
NGDBUILD_POST_UNISIM_SUMMARY
NGDBUILD_NUM_BUFG=2 | NGDBUILD_NUM_FDC=64 | NGDBUILD_NUM_FDCE=99 | NGDBUILD_NUM_FDE=1
NGDBUILD_NUM_FDP=1 | NGDBUILD_NUM_FDPE=1 | NGDBUILD_NUM_GND=2 | NGDBUILD_NUM_IBUF=4
NGDBUILD_NUM_IBUFG=2 | NGDBUILD_NUM_INV=12 | NGDBUILD_NUM_LD=19 | NGDBUILD_NUM_LUT1=63
NGDBUILD_NUM_LUT2=91 | NGDBUILD_NUM_LUT2_D=1 | NGDBUILD_NUM_LUT2_L=1 | NGDBUILD_NUM_LUT3=62
NGDBUILD_NUM_LUT3_D=1 | NGDBUILD_NUM_LUT3_L=7 | NGDBUILD_NUM_LUT4=131 | NGDBUILD_NUM_LUT4_D=1
NGDBUILD_NUM_LUT4_L=5 | NGDBUILD_NUM_MUXCY=172 | NGDBUILD_NUM_MUXF5=19 | NGDBUILD_NUM_OBUF=17
NGDBUILD_NUM_RAMB16_S4_S4=2 | NGDBUILD_NUM_VCC=2 | NGDBUILD_NUM_XORCY=140

XST Command Line Options
XST_OPTION_SUMMARY
-ifn=<fname>.prj | -ifmt=mixed | -ofn=<design_top> | -ofmt=NGC
-p=xc3s100e-4-cp132 | -top=<design_top> | -opt_mode=Speed | -opt_level=1
-iuc=NO | -keep_hierarchy=No | -netlist_hierarchy=As_Optimized | -rtlview=Yes
-glob_opt=AllClockNets | -read_cores=YES | -sd=<No customer specific name> | -write_timing_constraints=NO
-cross_clock_analysis=NO | -bus_delimiter=<> | -slice_utilization_ratio=100 | -bram_utilization_ratio=100
-verilog2001=YES | -fsm_extract=YES | -fsm_encoding=Auto | -safe_implementation=No
-fsm_style=LUT | -ram_extract=Yes | -ram_style=Auto | -rom_extract=Yes
-shreg_extract=YES | -rom_style=Auto | -auto_bram_packing=NO | -resource_sharing=YES
-async_to_sync=NO | -mult_style=Auto | -iobuf=YES | -max_fanout=100000
-bufg=24 | -register_duplication=YES | -register_balancing=No | -optimize_primitives=NO
-use_clock_enable=Yes | -use_sync_set=Yes | -use_sync_reset=Yes | -iob=Auto
-equivalent_register_removal=YES | -slice_utilization_ratio_maxmargin=5

ISim Statistics

Xilinx HDL Libraries Used=ieee, std, xilinxcorelib

Fuse Resource Usage=1437 ms, 45136 KB

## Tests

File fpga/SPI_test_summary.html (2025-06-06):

SPI_test Project Status
Project File: | TreUgers.xise | Parser Errors: | X 2 Errors
Module Name: | SPI_test | Implementation State: | New
Target Device: | xc3s100e-4cp132 | Errors:
Product Version: | ISE 14.1 | Warnings:
Design Goal: | Balanced | Routing Results:
Design Strategy: | Xilinx Default (unlocked) | Timing Constraints:
Environment: | | Final Timing Score:

Detailed Reports | | | | | | [-]
Report Name | Status | Generated | Errors | Warnings | Infos
Synthesis Report
Translation Report
Map Report
Place and Route Report
Power Report
Post-PAR Static Timing Report
Bitgen Report

Secondary Reports | | | [-]
Report Name | Status | Generated

Date Generated: 06/06/2025 - 13:31:51

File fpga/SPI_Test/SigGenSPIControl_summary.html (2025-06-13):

SigGenSPIControl Project Status (06/11/2025 - 09:45:00)
Project File: | SPI_Test.xise | Parser Errors: | No Errors
Module Name: | SigGenSPIControl | Implementation State: | Synthesized
Target Device: | xc3s100e-4cp132 | Errors: | No Errors
Product Version: | ISE 14.1 | Warnings: | 30 Warnings (30 new)
Design Goal: | Balanced | Routing Results:
Design Strategy: | Xilinx Default (unlocked) | Timing Constraints:
Environment: | System Settings | Final Timing Score:

Device Utilization Summary (estimated values) | | | | [-]
Logic Utilization | Used | Available | Utilization
Number of Slices | 4 | 960 | 0%
Number of Slice Flip Flops | 8 | 1920 | 0%
Number of 4 input LUTs | 8 | 1920 | 0%
Number of bonded IOBs | 30 | 83 | 36%
Number of GCLKs | 2 | 24 | 8%

Detailed Reports | | | | | | [-]
Report Name | Status | Generated | Errors | Warnings | Infos
Synthesis Report | Current | on 11. jun 09:44:59 2025 | 0 | 30 Warnings (30 new) | 6 Infos (6 new)
Translation Report | Out of Date | ti 10. jun 09:54:18 2025 | X 8 Errors (8 new) | 8 Warnings (0 new) | 0
Map Report
Place and Route Report
Power Report
Post-PAR Static Timing Report
Bitgen Report

Secondary Reports | | | [-]
Report Name | Status | Generated
ISIM Simulator Log | Current | to 12. jun 15:31:55 2025
WebTalk Log File | Out of Date | fr 6. jun 10:24:17 2025

Date Generated: 06/12/2025 - 15:48:44

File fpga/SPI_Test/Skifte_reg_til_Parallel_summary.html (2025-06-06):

Skifte_reg_til_Parallel Project Status (06/06/2025 - 15:52:41)
Project File: | SPI_Test.xise | Parser Errors: | No Errors
Module Name: | Skifte_reg_til_Parallel | Implementation State: | Synthesized
Target Device: | xc3s100e-4cp132 | Errors:
Product Version: | ISE 14.1 | Warnings:
Design Goal: | Balanced | Routing Results:
Design Strategy: | Xilinx Default (unlocked) | Timing Constraints:
Environment: | System Settings | Final Timing Score:

Device Utilization Summary (estimated values) | | | | [-]
Logic Utilization | Used | Available | Utilization
Number of Slices | 4 | 960 | 0%
Number of Slice Flip Flops | 8 | 1920 | 0%
Number of 4 input LUTs | 1 | 1920 | 0%
Number of bonded IOBs | 13 | 83 | 15%
Number of GCLKs | 1 | 24 | 4%

Detailed Reports | | | | | | [-]
Report Name | Status | Generated | Errors | Warnings | Infos
Synthesis Report | Current | fr 6. jun 13:46:20 2025
Translation Report | Out of Date | fr 6. jun 10:24:16 2025 | 0 | 0 | 0
Map Report | Out of Date | fr 6. jun 10:24:16 2025 | 0 | 0 | 2 Infos (0 new)
Place and Route Report | Out of Date | fr 6. jun 10:24:16 2025 | 0 | 1 Warning (0 new) | 2 Infos (0 new)
Power Report
Post-PAR Static Timing Report | Out of Date | fr 6. jun 10:24:16 2025 | 0 | 0 | 6 Infos (0 new)
Bitgen Report | Out of Date | fr 6. jun 10:24:17 2025

Secondary Reports | | | [-]
Report Name | Status | Generated
ISIM Simulator Log | Current | fr 6. jun 13:47:53 2025
WebTalk Log File | Out of Date | fr 6. jun 10:24:17 2025

Date Generated: 06/06/2025 - 15:52:41

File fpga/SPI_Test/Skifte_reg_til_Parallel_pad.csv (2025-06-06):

#Release 14.1 - par P.15xf (nt64)
#Copyright (c) 1995-2012 Xilinx | Inc. All rights reserved.
#Fri Jun 06 10:07:32 2025
#
## NOTE: This file is designed to be imported into a spreadsheet program
# such as Microsoft Excel for viewing | printing and sorting. The
# character is used as the data field separator. This file is also designed
# to support parsing.
#
#INPUT FILE: Skifte_reg_til_Parallel_map.ncd
#OUTPUT FILE: Skifte_reg_til_Parallel_pad.csv
#PART TYPE: xc3s100e
#SPEED GRADE: -4
#PACKAGE: cp132
#
# Pinout by Pin Number:
#
# ----- | ----- | ----- | ----- | ----- | ----- | ----- | ----- | ----- | ----- | ----- | ----- | ----- | ----- | -----
Pin Number | Signal Name | Pin Usage | Pin Name | Direction | IO Standard | IO Bank Number | Drive (mA) | Slew Rate | Termination | IOB Delay | Voltage | Constraint | IO Register | Signal Integrity
A1 |  |  | PROG_B
A2 |  |  | TDI
A3 | SCK | IBUF | IO_L11P_0 | INPUT | LVCMOS25* | 0 |  |  |  | NONE |  | LOCATED | NO | NONE
A4 |  |  | NC
A5 |  |  | VCCAUX |  |  |  |  |  |  |  | 2.5
A6 |  |  | VCCO_0 |  |  | 0 |  |  |  |  | 2.50
A7 |  | DIFFM | IO_L07P_0/GCLK10 | UNUSED |  | 0
A8 |  |  | GND
A9 |  | DIFFS | IO_L05N_0/GCLK7 | UNUSED |  | 0
A10 |  | DIFFM | IO_L04P_0/GCLK4 | UNUSED |  | 0
A11 |  |  | VCCINT |  |  |  |  |  |  |  | 1.2
A12 |  |  | NC
A13 |  | DIFFM | IO_L01P_0 | UNUSED |  | 0
A14 |  |  | TDO
B1 |  | DIFFS | IO_L01N_3 | UNUSED |  | 3
B2 | MOSI | IBUF | IO_L01P_3 | INPUT | LVCMOS25* | 3 |  |  |  | NONE |  | LOCATED | NO | NONE
B3 |  | DIFFS | IO_L11N_0/HSWAP | UNUSED |  | 0
B4 |  | IBUF | IP | UNUSED |  | 0
B5 |  | DIFFM | IO_L09P_0 | UNUSED |  | 0
B6 |  | DIFFM | IO_L08P_0 | UNUSED |  | 0
B7 |  | DIFFS | IO_L07N_0/GCLK11 | UNUSED |  | 0
B8 |  | DIFFMI | IP_L06P_0/GCLK8 | UNUSED |  | 0
B9 |  | DIFFM | IO_L05P_0/GCLK6 | UNUSED |  | 0
B10 |  |  | VCCO_0 |  |  | 0 |  |  |  |  | 2.50
B11 |  |  | NC
B12 |  |  | NC
B13 |  |  | TCK
B14 |  |  | TMS
C1 |  |  | NC
C2 |  | DIFFS | IO_L02N_3 | UNUSED |  | 3
C3 |  | DIFFM | IO_L02P_3 | UNUSED |  | 3
C4 |  |  | NC
C5 |  | DIFFS | IO_L09N_0 | UNUSED |  | 0
C6 |  | DIFFS | IO_L08N_0/VREF_0 | UNUSED |  | 0
C7 |  |  | GND
C8 |  | DIFFSI | IP_L06N_0/GCLK9 | UNUSED |  | 0
C9 |  | DIFFS | IO_L04N_0/GCLK5 | UNUSED |  | 0
C10 |  |  | GND
C11 |  | IBUF | IP | UNUSED |  | 0
C12 |  | DIFFS | IO_L01N_0 | UNUSED |  | 0
C13 |  | DIFFS | IO_L10N_1/LDC2 | UNUSED |  | 1
C14 |  | DIFFM | IO_L10P_1/LDC1 | UNUSED |  | 1
D1 |  |  | NC
D2 |  | IOB | IO | UNUSED |  | 3
D3 |  |  | VCCINT |  |  |  |  |  |  |  | 1.2
D12 |  | DIFFS | IO_L09N_1/LDC0 | UNUSED |  | 1
D13 |  | DIFFM | IO_L09P_1/HDC | UNUSED |  | 1
D14 |  |  | NC
E1 |  |  | VCCO_3 |  |  | 3 |  |  |  |  | 2.50
E2 |  | IBUF | IP/VREF_3 | UNUSED |  | 3
E3 |  |  | GND
E12 |  |  | VCCAUX |  |  |  |  |  |  |  | 2.5
E13 |  |  | VCCO_1 |  |  | 1 |  |  |  |  | any******
E14 |  |  | GND
F1 |  | DIFFM | IO_L05P_3/LHCLK2 | UNUSED |  | 3
F2 |  | DIFFS | IO_L04N_3/LHCLK1 | UNUSED |  | 3
F3 |  | DIFFM | IO_L04P_3/LHCLK0 | UNUSED |  | 3
F12 |  | IOB | IO/A0 | UNUSED |  | 1
F13 |  | DIFFS | IO_L08N_1/A1 | UNUSED |  | 1
F14 |  | DIFFM | IO_L08P_1/A2 | UNUSED |  | 1
G1 | LED<7> | IOB | IO_L05N_3/LHCLK3/IRDY2 | TRISTATE | LVCMOS25* | 3 | 12 | SLOW | NONE** |  |  | LOCATED | YES | NONE
G2 |  |  | GND
G3 |  | DIFFM | IO_L06P_3/LHCLK4/TRDY2 | UNUSED |  | 3
G12 |  | IBUF | IP/VREF_1 | UNUSED |  | 1
G13 |  | DIFFS | IO_L07N_1/A3/RHCLK7 | UNUSED |  | 1
G14 |  | DIFFM | IO_L07P_1/A4/RHCLK6 | UNUSED |  | 1
H1 |  | DIFFS | IO_L06N_3/LHCLK5 | UNUSED |  | 3
H2 |  | DIFFM | IO_L07P_3/LHCLK6 | UNUSED |  | 3
H3 |  | DIFFS | IO_L07N_3/LHCLK7 | UNUSED |  | 3
H12 |  | DIFFS | IO_L06N_1/A5/RHCLK5 | UNUSED |  | 1
H13 |  | DIFFM | IO_L06P_1/A6/RHCLK4/IRDY1 | UNUSED |  | 1
H14 |  |  | GND
J1 |  |  | GND
J2 |  |  | VCCO_3 |  |  | 3 |  |  |  |  | 2.50
J3 | SSnot | IBUF | IO | INPUT | LVCMOS25* | 3 |  |  |  | NONE |  | LOCATED | NO | NONE
J12 |  | DIFFS | IO_L04N_1/A9/RHCLK1 | UNUSED |  | 1
J13 |  | DIFFM | IO_L05P_1/A8/RHCLK2 | UNUSED |  | 1
J14 |  | DIFFS | IO_L05N_1/A7/RHCLK3/TRDY1 | UNUSED |  | 1
K1 |  |  | VCCAUX |  |  |  |  |  |  |  | 2.5
K2 |  |  | NC
K3 |  | IBUF | IP/VREF_3 | UNUSED |  | 3
K12 |  |  | GND
K13 |  | IOB | IO/VREF_1 | UNUSED |  | 1
K14 |  | DIFFM | IO_L04P_1/A10/RHCLK0 | UNUSED |  | 1
L1 |  | DIFFM | IO_L08P_3 | UNUSED |  | 3
L2 |  | DIFFS | IO_L08N_3 | UNUSED |  | 3
L3 |  | DIFFM | IO_L09P_3 | UNUSED |  | 3
L12 |  |  | VCCINT |  |  |  |  |  |  |  | 1.2
L13 |  | DIFFM | IO_L03P_1/A12 | UNUSED |  | 1
L14 |  | DIFFS | IO_L03N_1/A11 | UNUSED |  | 1
M1 |  | DIFFS | IO_L09N_3 | UNUSED |  | 3
M2 |  | DIFFM | IO_L01P_2/CSO_B | UNUSED |  | 2
M3 |  |  | GND
M4 | RESET | IBUF | IO_L03P_2/D7/GCLK12 | INPUT | LVCMOS25* | 2 |  |  |  | NONE |  | UNLOCATED | NO | NONE
M5 | LED<0> | IOB | IO_L04P_2/D4/GCLK14 | TRISTATE | LVCMOS25* | 2 | 12 | SLOW | NONE** |  |  | LOCATED | NO | NONE
M6 |  | DIFFMI | IP_L05P_2/RDWR_B/GCLK0 | UNUSED |  | 2
M7 |  |  | GND
M8 |  |  | VCCO_2 |  |  | 2 |  |  |  |  | 2.50
M9 |  |  | NC
M10 |  |  | NC
M11 | LED<1> | IOB | IO_L10N_2/VS1/A18 | TRISTATE | LVCMOS25* | 2 | 12 | SLOW | NONE** |  |  | LOCATED | NO | NONE
M12 |  | DIFFM | IO_L02P_1/A14 | UNUSED |  | 1
M13 |  | DIFFS | IO_L02N_1/A13 | UNUSED |  | 1
M14 |  |  | VCCO_1 |  |  | 1 |  |  |  |  | any******
N1 |  | DIFFS | IO_L01N_2/INIT_B | UNUSED |  | 2
N2 |  | DIFFS | IO_L02N_2/MOSI/CSI_B | UNUSED |  | 2
N3 |  | DIFFSI | IP/VREF_2 | UNUSED |  | 2
N4 | LED<5> | IOB | IO_L03N_2/D6/GCLK13 | TRISTATE | LVCMOS25* | 2 | 12 | SLOW | NONE** |  |  | LOCATED | NO | NONE
N5 | LED<4> | IOB | IO_L04N_2/D3/GCLK15 | TRISTATE | LVCMOS25* | 2 | 12 | SLOW | NONE** |  |  | LOCATED | NO | NONE
N6 |  | DIFFSI | IP_L05N_2/M2/GCLK1 | UNUSED |  | 2
N7 |  | IOB | IO/M1 | UNUSED |  | 2
N8 |  | DIFFS | IO_L07N_2/DIN/D0 | UNUSED |  | 2
N9 |  |  | NC
N10 |  |  | NC
N11 |  | DIFFM | IO_L10P_2/VS2/A19 | UNUSED |  | 2
N12 |  | DIFFS | IO_L11N_2/CCLK | UNUSED |  | 2
N13 |  | DIFFM | IO_L01P_1/A16 | UNUSED |  | 1
N14 |  | DIFFS | IO_L01N_1/A15 | UNUSED |  | 1
P1 |  | DIFFM | IO_L02P_2/DOUT/BUSY | UNUSED |  | 2
P2 |  |  | VCCINT |  |  |  |  |  |  |  | 1.2
P3 |  |  | VCCO_2 |  |  | 2 |  |  |  |  | 2.50
P4 | LED<6> | IOB | IO/D5 | TRISTATE | LVCMOS25* | 2 | 12 | SLOW | NONE** |  |  | LOCATED | NO | NONE
P5 |  |  | GND
P6 | LED<3> | IOB | IO_L06P_2/D2/GCLK2 | TRISTATE | LVCMOS25* | 2 | 12 | SLOW | NONE** |  |  | LOCATED | NO | NONE
P7 | LED<2> | IOB | IO_L06N_2/D1/GCLK3 | TRISTATE | LVCMOS25* | 2 | 12 | SLOW | NONE** |  |  | LOCATED | NO | NONE
P8 |  | DIFFM | IO_L07P_2/M0 | UNUSED |  | 2
P9 |  |  | VCCAUX |  |  |  |  |  |  |  | 2.5
P10 |  |  | NC
P11 |  | IBUF | IP/VREF_2 | UNUSED |  | 2
P12 |  | DIFFM | IO_L11P_2/VS0/A17 | UNUSED |  | 2
P13 |  |  | DONE
P14 |  |  | GND
# ----- | ----- | ----- | ----- | ----- | ----- | ----- | ----- | ----- | ----- | ----- | ----- | ----- | ----- | -----
#
#* Default value.
#** This default Pullup/Pulldown value can be overridden in Bitgen.
#****** Special VCCO requirements may apply. Please consult the device
# family datasheet for specific guideline on VCCO requirements.
#
#
#

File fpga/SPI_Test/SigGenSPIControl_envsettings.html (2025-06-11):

System Settings

Environment Settings
Environment Variable | xst | ngdbuild | map | par
PATHEXT | .COM; .EXE; .BAT; .CMD; .VBS; .VBE; .JS; .JSE; .WSF; .WSH; .MSC | .COM; .EXE; .BAT; .CMD; .VBS; .VBE; .JS; .JSE; .WSF; .WSH; .MSC | < data not available > | < data not available >

Path

P:\Xilinx\14.1\ISE_DS\ISE\\lib\nt64;
P:\Xilinx\14.1\ISE_DS\ISE\\bin\nt64;
P:\Xilinx\14.1\ISE_DS\ISE\bin\nt64;
P:\Xilinx\14.1\ISE_DS\ISE\lib\nt64;
P:\Xilinx\Vivado\2012.1\bin;
P:\Xilinx\14.1\ISE_DS\EDK\bin\nt64;
P:\Xilinx\14.1\ISE_DS\EDK\lib\nt64;
P:\Xilinx\14.1\ISE_DS\EDK\gnu\microblaze\nt64\bin;
P:\Xilinx\14.1\ISE_DS\EDK\gnu\powerpc-eabi\nt64\bin;
P:\Xilinx\14.1\ISE_DS\EDK\gnuwin\bin;
P:\Xilinx\14.1\ISE_DS\EDK\gnu\arm\nt64\bin;
P:\Xilinx\14.1\ISE_DS\common\bin\nt64;
P:\Xilinx\14.1\ISE_DS\common\lib\nt64;
C:\Program Files (x86)\NVIDIA Corporation\PhysX\Common;
C:\WINDOWS\system32;
C:\WINDOWS;
C:\WINDOWS\System32\Wbem;
C:\WINDOWS\System32\WindowsPowerShell\v1.0\;
C:\WINDOWS\System32\OpenSSH\;
C:\Program Files (x86)\IVI Foundation\VISA\WinNT\Bin\;
C:\Program Files\IVI Foundation\VISA\Win64\Bin\;
C:\Program Files (x86)\IVI Foundation\VISA\WinNT\Bin;
C:\Program Files (x86)\Windows Kits\8.1\Windows Performance Toolkit\;
M:\Commands;
C:\Program Files\Matlab R2019a\runtime\win64;
C:\Program Files\Matlab R2019a\bin;
C:\Users\s240324\AppData\Local\Microsoft\WindowsApps;
C:\Users\s240324\AppData\Local\Programs\Git\cmd

P:\Xilinx\14.1\ISE_DS\ISE\\lib\nt64;
P:\Xilinx\14.1\ISE_DS\ISE\\bin\nt64;
P:\Xilinx\14.1\ISE_DS\ISE\bin\nt64;
P:\Xilinx\14.1\ISE_DS\ISE\lib\nt64;
P:\Xilinx\Vivado\2012.1\bin;
P:\Xilinx\14.1\ISE_DS\EDK\bin\nt64;
P:\Xilinx\14.1\ISE_DS\EDK\lib\nt64;
P:\Xilinx\14.1\ISE_DS\EDK\gnu\microblaze\nt64\bin;
P:\Xilinx\14.1\ISE_DS\EDK\gnu\powerpc-eabi\nt64\bin;
P:\Xilinx\14.1\ISE_DS\EDK\gnuwin\bin;
P:\Xilinx\14.1\ISE_DS\EDK\gnu\arm\nt64\bin;
P:\Xilinx\14.1\ISE_DS\common\bin\nt64;
P:\Xilinx\14.1\ISE_DS\common\lib\nt64;
C:\Program Files (x86)\NVIDIA Corporation\PhysX\Common;
C:\WINDOWS\system32;
C:\WINDOWS;
C:\WINDOWS\System32\Wbem;
C:\WINDOWS\System32\WindowsPowerShell\v1.0\;
C:\WINDOWS\System32\OpenSSH\;
C:\Program Files (x86)\IVI Foundation\VISA\WinNT\Bin\;
C:\Program Files\IVI Foundation\VISA\Win64\Bin\;
C:\Program Files (x86)\IVI Foundation\VISA\WinNT\Bin;
C:\Program Files (x86)\Windows Kits\8.1\Windows Performance Toolkit\;
M:\Commands;
C:\Program Files\Matlab R2019a\runtime\win64;
C:\Program Files\Matlab R2019a\bin;
C:\Users\s240324\AppData\Local\Microsoft\WindowsApps;
C:\Users\s240324\AppData\Local\Programs\Git\cmd

< data not available >

< data not available >
XILINX | P:\Xilinx\14.1\ISE_DS\ISE\ | P:\Xilinx\14.1\ISE_DS\ISE\ | < data not available > | < data not available >
XILINXD_LICENSE_FILE | 2100@xilinx.winbar.dtu.dk | 2100@xilinx.winbar.dtu.dk | < data not available > | < data not available >
XILINX_DSP | P:\Xilinx\14.1\ISE_DS\ISE | P:\Xilinx\14.1\ISE_DS\ISE | < data not available > | < data not available >
XILINX_EDK | P:\Xilinx\14.1\ISE_DS\EDK | P:\Xilinx\14.1\ISE_DS\EDK | < data not available > | < data not available >
XILINX_VIVADO | P:\Xilinx\Vivado\2012.1 | P:\Xilinx\Vivado\2012.1 | < data not available > | < data not available >

Synthesis Property Settings
Switch Name | Property Name | Value | Default Value
-ifn | | SigGenSPIControl.prj
-ifmt | | mixed | MIXED
-ofn | | SigGenSPIControl
-ofmt | | NGC | NGC
-p | | xc3s100e-4-cp132
-top | | SigGenSPIControl
-opt_mode | Optimization Goal | Speed | SPEED
-opt_level | Optimization Effort | 1 | 1
-iuc | Use synthesis Constraints File | NO | NO
-keep_hierarchy | Keep Hierarchy | No | NO
-netlist_hierarchy | Netlist Hierarchy | As_Optimized | as_optimized
-rtlview | Generate RTL Schematic | Yes | NO
-glob_opt | Global Optimization Goal | AllClockNets | ALLCLOCKNETS
-read_cores | Read Cores | YES | YES
-write_timing_constraints | Write Timing Constraints | NO | NO
-cross_clock_analysis | Cross Clock Analysis | NO | NO
-bus_delimiter | Bus Delimiter | <> | <>
-slice_utilization_ratio | Slice Utilization Ratio | 100 | 100%
-bram_utilization_ratio | BRAM Utilization Ratio | 100 | 100%
-verilog2001 | Verilog 2001 | YES | YES
-fsm_extract | | YES | YES
-fsm_encoding | | Auto | AUTO
-safe_implementation | | No | NO
-fsm_style | | LUT | LUT
-ram_extract | | Yes | YES
-ram_style | | Auto | AUTO
-rom_extract | | Yes | YES
-shreg_extract | | YES | YES
-rom_style | | Auto | AUTO
-auto_bram_packing | | NO | NO
-resource_sharing | | YES | YES
-async_to_sync | | NO | NO
-mult_style | | Auto | AUTO
-iobuf | | YES | YES
-max_fanout | | 100000 | 500
-bufg | | 24 | 24
-register_duplication | | YES | YES
-register_balancing | | No | NO
-optimize_primitives | | NO | NO
-use_clock_enable | | Yes | YES
-use_sync_set | | Yes | YES
-use_sync_reset | | Yes | YES
-iob | | Auto | AUTO
-equivalent_register_removal | | YES | YES
-slice_utilization_ratio_maxmargin | | 5 | 0%

Translation Property Settings
Switch Name | Property Name | Value | Default Value
-intstyle | | ise | None
-dd | | _ngo | None
-p | | xc3s100e-cp132-4 | None
-uc | | Top_counter.ucf | None

Operating System Information
Operating System Information | xst | ngdbuild | map | par
CPU Architecture/Speed | Intel(R) Core(TM) i7-6700T CPU @ 2.80GHz/2808 MHz | Intel(R) Core(TM) i7-6700T CPU @ 2.80GHz/2808 MHz | < data not available > | < data not available >
Host | DTU-CZC62978DR | DTU-CZC62978DR | < data not available > | < data not available >
OS Name | Microsoft , 64-bit | Microsoft , 64-bit | < data not available > | < data not available >
OS Release | major release (build 9200) | major release (build 9200) | < data not available > | < data not available >

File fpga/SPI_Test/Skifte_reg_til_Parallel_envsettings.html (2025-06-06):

System Settings

Environment Settings
Environment Variable | xst | ngdbuild | map | par
PATHEXT | .COM; .EXE; .BAT; .CMD; .VBS; .VBE; .JS; .JSE; .WSF; .WSH; .MSC | .COM; .EXE; .BAT; .CMD; .VBS; .VBE; .JS; .JSE; .WSF; .WSH; .MSC | .COM; .EXE; .BAT; .CMD; .VBS; .VBE; .JS; .JSE; .WSF; .WSH; .MSC | .COM; .EXE; .BAT; .CMD; .VBS; .VBE; .JS; .JSE; .WSF; .WSH; .MSC

Path

P:\Xilinx\14.1\ISE_DS\ISE\\lib\nt64;
P:\Xilinx\14.1\ISE_DS\ISE\\bin\nt64;
C:\Program Files (x86)\Xilinx\14.1\ISE_DS\ISE\bin\nt64;
C:\Program Files (x86)\Xilinx\14.1\ISE_DS\ISE\lib\nt64;
C:\Program Files (x86)\Xilinx\Vivado\2012.1\bin;
C:\Program Files (x86)\Xilinx\14.1\ISE_DS\EDK\bin\nt64;
C:\Program Files (x86)\Xilinx\14.1\ISE_DS\EDK\lib\nt64;
C:\Program Files (x86)\Xilinx\14.1\ISE_DS\EDK\gnu\microblaze\nt64\bin;
C:\Program Files (x86)\Xilinx\14.1\ISE_DS\EDK\gnu\powerpc-eabi\nt64\bin;
C:\Program Files (x86)\Xilinx\14.1\ISE_DS\EDK\gnuwin\bin;
C:\Program Files (x86)\Xilinx\14.1\ISE_DS\EDK\gnu\arm\nt64\bin;
C:\Program Files (x86)\Xilinx\14.1\ISE_DS\common\bin\nt64;
C:\Program Files (x86)\Xilinx\14.1\ISE_DS\common\lib\nt64;
C:\Program Files (x86)\NVIDIA Corporation\PhysX\Common;
C:\WINDOWS\system32;
C:\WINDOWS;
C:\WINDOWS\System32\Wbem;
C:\WINDOWS\System32\WindowsPowerShell\v1.0\;
C:\WINDOWS\System32\OpenSSH\;
C:\Program Files (x86)\IVI Foundation\VISA\WinNT\Bin\;
C:\Program Files\IVI Foundation\VISA\Win64\Bin\;
C:\Program Files (x86)\IVI Foundation\VISA\WinNT\Bin;
C:\Program Files (x86)\Windows Kits\8.1\Windows Performance Toolkit\;
M:\Commands;
C:\Program Files\Matlab R2019a\runtime\win64;
C:\Program Files\Matlab R2019a\bin;
C:\Users\s240324\AppData\Local\Microsoft\WindowsApps;
C:\Users\s240324\AppData\Local\Programs\Git\cmd

P:\Xilinx\14.1\ISE_DS\ISE\\lib\nt64;
P:\Xilinx\14.1\ISE_DS\ISE\\bin\nt64;
C:\Program Files (x86)\Xilinx\14.1\ISE_DS\ISE\bin\nt64;
C:\Program Files (x86)\Xilinx\14.1\ISE_DS\ISE\lib\nt64;
C:\Program Files (x86)\Xilinx\Vivado\2012.1\bin;
C:\Program Files (x86)\Xilinx\14.1\ISE_DS\EDK\bin\nt64;
C:\Program Files (x86)\Xilinx\14.1\ISE_DS\EDK\lib\nt64;
C:\Program Files (x86)\Xilinx\14.1\ISE_DS\EDK\gnu\microblaze\nt64\bin;
C:\Program Files (x86)\Xilinx\14.1\ISE_DS\EDK\gnu\powerpc-eabi\nt64\bin;
C:\Program Files (x86)\Xilinx\14.1\ISE_DS\EDK\gnuwin\bin;
C:\Program Files (x86)\Xilinx\14.1\ISE_DS\EDK\gnu\arm\nt64\bin;
C:\Program Files (x86)\Xilinx\14.1\ISE_DS\common\bin\nt64;
C:\Program Files (x86)\Xilinx\14.1\ISE_DS\common\lib\nt64;
C:\Program Files (x86)\NVIDIA Corporation\PhysX\Common;
C:\WINDOWS\system32;
C:\WINDOWS;
C:\WINDOWS\System32\Wbem;
C:\WINDOWS\System32\WindowsPowerShell\v1.0\;
C:\WINDOWS\System32\OpenSSH\;
C:\Program Files (x86)\IVI Foundation\VISA\WinNT\Bin\;
C:\Program Files\IVI Foundation\VISA\Win64\Bin\;
C:\Program Files (x86)\IVI Foundation\VISA\WinNT\Bin;
C:\Program Files (x86)\Windows Kits\8.1\Windows Performance Toolkit\;
M:\Commands;
C:\Program Files\Matlab R2019a\runtime\win64;
C:\Program Files\Matlab R2019a\bin;
C:\Users\s240324\AppData\Local\Microsoft\WindowsApps;
C:\Users\s240324\AppData\Local\Programs\Git\cmd

P:\Xilinx\14.1\ISE_DS\ISE\\lib\nt64;
P:\Xilinx\14.1\ISE_DS\ISE\\bin\nt64;
C:\Program Files (x86)\Xilinx\14.1\ISE_DS\ISE\bin\nt64;
C:\Program Files (x86)\Xilinx\14.1\ISE_DS\ISE\lib\nt64;
C:\Program Files (x86)\Xilinx\Vivado\2012.1\bin;
C:\Program Files (x86)\Xilinx\14.1\ISE_DS\EDK\bin\nt64;
C:\Program Files (x86)\Xilinx\14.1\ISE_DS\EDK\lib\nt64;
C:\Program Files (x86)\Xilinx\14.1\ISE_DS\EDK\gnu\microblaze\nt64\bin;
C:\Program Files (x86)\Xilinx\14.1\ISE_DS\EDK\gnu\powerpc-eabi\nt64\bin;
C:\Program Files (x86)\Xilinx\14.1\ISE_DS\EDK\gnuwin\bin;
C:\Program Files (x86)\Xilinx\14.1\ISE_DS\EDK\gnu\arm\nt64\bin;
C:\Program Files (x86)\Xilinx\14.1\ISE_DS\common\bin\nt64;
C:\Program Files (x86)\Xilinx\14.1\ISE_DS\common\lib\nt64;
C:\Program Files (x86)\NVIDIA Corporation\PhysX\Common;
C:\WINDOWS\system32;
C:\WINDOWS;
C:\WINDOWS\System32\Wbem;
C:\WINDOWS\System32\WindowsPowerShell\v1.0\;
C:\WINDOWS\System32\OpenSSH\;
C:\Program Files (x86)\IVI Foundation\VISA\WinNT\Bin\;
C:\Program Files\IVI Foundation\VISA\Win64\Bin\;
C:\Program Files (x86)\IVI Foundation\VISA\WinNT\Bin;
C:\Program Files (x86)\Windows Kits\8.1\Windows Performance Toolkit\;
M:\Commands;
C:\Program Files\Matlab R2019a\runtime\win64;
C:\Program Files\Matlab R2019a\bin;
C:\Users\s240324\AppData\Local\Microsoft\WindowsApps;
C:\Users\s240324\AppData\Local\Programs\Git\cmd

P:\Xilinx\14.1\ISE_DS\ISE\\lib\nt64;
P:\Xilinx\14.1\ISE_DS\ISE\\bin\nt64;
C:\Program Files (x86)\Xilinx\14.1\ISE_DS\ISE\bin\nt64;
C:\Program Files (x86)\Xilinx\14.1\ISE_DS\ISE\lib\nt64;
C:\Program Files (x86)\Xilinx\Vivado\2012.1\bin;
C:\Program Files (x86)\Xilinx\14.1\ISE_DS\EDK\bin\nt64;
C:\Program Files (x86)\Xilinx\14.1\ISE_DS\EDK\lib\nt64;
C:\Program Files (x86)\Xilinx\14.1\ISE_DS\EDK\gnu\microblaze\nt64\bin;
C:\Program Files (x86)\Xilinx\14.1\ISE_DS\EDK\gnu\powerpc-eabi\nt64\bin;
C:\Program Files (x86)\Xilinx\14.1\ISE_DS\EDK\gnuwin\bin;
C:\Program Files (x86)\Xilinx\14.1\ISE_DS\EDK\gnu\arm\nt64\bin;
C:\Program Files (x86)\Xilinx\14.1\ISE_DS\common\bin\nt64;
C:\Program Files (x86)\Xilinx\14.1\ISE_DS\common\lib\nt64;
C:\Program Files (x86)\NVIDIA Corporation\PhysX\Common;
C:\WINDOWS\system32;
C:\WINDOWS;
C:\WINDOWS\System32\Wbem;
C:\WINDOWS\System32\WindowsPowerShell\v1.0\;
C:\WINDOWS\System32\OpenSSH\;
C:\Program Files (x86)\IVI Foundation\VISA\WinNT\Bin\;
C:\Program Files\IVI Foundation\VISA\Win64\Bin\;
C:\Program Files (x86)\IVI Foundation\VISA\WinNT\Bin;
C:\Program Files (x86)\Windows Kits\8.1\Windows Performance Toolkit\;
M:\Commands;
C:\Program Files\Matlab R2019a\runtime\win64;
C:\Program Files\Matlab R2019a\bin;
C:\Users\s240324\AppData\Local\Microsoft\WindowsApps;
C:\Users\s240324\AppData\Local\Programs\Git\cmd
XILINX | P:\Xilinx\14.1\ISE_DS\ISE\ | P:\Xilinx\14.1\ISE_DS\ISE\ | P:\Xilinx\14.1\ISE_DS\ISE\ | P:\Xilinx\14.1\ISE_DS\ISE\
XILINXD_LICENSE_FILE | 2100@xilinx.winbar.dtu.dk | 2100@xilinx.winbar.dtu.dk | 2100@xilinx.winbar.dtu.dk | 2100@xilinx.winbar.dtu.dk
XILINX_DSP | C:\Program Files (x86)\Xilinx\14.1\ISE_DS\ISE | C:\Program Files (x86)\Xilinx\14.1\ISE_DS\ISE | C:\Program Files (x86)\Xilinx\14.1\ISE_DS\ISE | C:\Program Files (x86)\Xilinx\14.1\ISE_DS\ISE
XILINX_EDK | C:\Program Files (x86)\Xilinx\14.1\ISE_DS\EDK | C:\Program Files (x86)\Xilinx\14.1\ISE_DS\EDK | C:\Program Files (x86)\Xilinx\14.1\ISE_DS\EDK | C:\Program Files (x86)\Xilinx\14.1\ISE_DS\EDK
XILINX_VIVADO | C:\Program Files (x86)\Xilinx\Vivado\2012.1 | C:\Program Files (x86)\Xilinx\Vivado\2012.1 | C:\Program Files (x86)\Xilinx\Vivado\2012.1 | C:\Program Files (x86)\Xilinx\Vivado\2012.1

Synthesis Property Settings
Switch Name | Property Name | Value | Default Value
-ifn | | Skifte_reg_til_Parallel.prj
-ifmt | | mixed | MIXED
-ofn | | Skifte_reg_til_Parallel
-ofmt | | NGC | NGC
-p | | xc3s100e-4-cp132
-top | | Skifte_reg_til_Parallel
-opt_mode | Optimization Goal | Speed | SPEED
-opt_level | Optimization Effort | 1 | 1
-iuc | Use synthesis Constraints File | NO | NO
-keep_hierarchy | Keep Hierarchy | No | NO
-netlist_hierarchy | Netlist Hierarchy | As_Optimized | as_optimized
-rtlview | Generate RTL Schematic | Yes | NO
-glob_opt | Global Optimization Goal | AllClockNets | ALLCLOCKNETS
-read_cores | Read Cores | YES | YES
-write_timing_constraints | Write Timing Constraints | NO | NO
-cross_clock_analysis | Cross Clock Analysis | NO | NO
-bus_delimiter | Bus Delimiter | <> | <>
-slice_utilization_ratio | Slice Utilization Ratio | 100 | 100%
-bram_utilization_ratio | BRAM Utilization Ratio | 100 | 100%
-verilog2001 | Verilog 2001 | YES | YES
-fsm_extract | | YES | YES
-fsm_encoding | | Auto | AUTO
-safe_implementation | | No | NO
-fsm_style | | LUT | LUT
-ram_extract | | Yes | YES
-ram_style | | Auto | AUTO
-rom_extract | | Yes | YES
-shreg_extract | | YES | YES
-rom_style | | Auto | AUTO
-auto_bram_packing | | NO | NO
-resource_sharing | | YES | YES
-async_to_sync | | NO | NO
-mult_style | | Auto | AUTO
-iobuf | | YES | YES
-max_fanout | | 100000 | 500
-bufg | | 24 | 24
-register_duplication | | YES | YES
-register_balancing | | No | NO
-optimize_primitives | | NO | NO
-use_clock_enable | | Yes | YES
-use_sync_set | | Yes | YES
-use_sync_reset | | Yes | YES
-iob | | Auto | AUTO
-equivalent_register_removal | | YES | YES
-slice_utilization_ratio_maxmargin | | 5 | 0%

Translation Property Settings
Switch Name | Property Name | Value | Default Value
-intstyle | | ise | None
-dd | | _ngo | None
-p | | xc3s100e-cp132-4 | None
-uc | | Top_counter.ucf | None

Map Property Settings
Switch Name | Property Name | Value | Default Value
-ir | Use RLOC Constraints | OFF | OFF
-cm | Optimization Strategy (Cover Mode) | area | area
-intstyle | | ise | None
-o | | Skifte_reg_til_Parallel_map.ncd | None
-pr | Pack I/O Registers/Latches into IOBs | off | off
-p | | xc3s100e-cp132-4 | None

Place and Route Property Settings
Switch Name | Property Name | Value | Default Value
-t | | 1 | 1
-intstyle | | ise
-ol | Place & Route Effort Level (Overall) | high | std
-w | | true | false

Operating System Information
Operating System Information | xst | ngdbuild | map | par
CPU Architecture/Speed | Intel(R) Core(TM) i7-6700T CPU @ 2.80GHz/2808 MHz | Intel(R) Core(TM) i7-6700T CPU @ 2.80GHz/2808 MHz | Intel(R) Core(TM) i7-6700T CPU @ 2.80GHz/2808 MHz | Intel(R) Core(TM) i7-6700T CPU @ 2.80GHz/2808 MHz
Host | DTU-CZC62978DR | DTU-CZC62978DR | DTU-CZC62978DR | DTU-CZC62978DR
OS Name | Microsoft , 64-bit | Microsoft , 64-bit | Microsoft , 64-bit | Microsoft , 64-bit
OS Release | major release (build 9200) | major release (build 9200) | major release (build 9200) | major release (build 9200)

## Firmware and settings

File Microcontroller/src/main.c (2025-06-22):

// ## Program developed by Mads Rodulph and Sigurd Hestbech Christiansen ##
// ## Last edited: 20-6-2025 ##
// ## Throughout the code, page references are marked as S.xxx, referring to the Atmega2560 datasheet. ##

#ifndef F_CPU
#define F_CPU 16000000UL // Define CPU frequency
#endif

#include <avr/io.h>        // Include I/O functions
#include <stdio.h>         // Include sprintf
#include <stdbool.h>       // Include boolean support
#include <avr/interrupt.h> // Include interrupt handling
#include <stdint.h>        // Include fixed width integer types
#include <util/delay.h>    // Includes delay function
#include "ADC.h"           // Include ADC initialization functions
#include "SPI.h"           // Include SPI init functions
#include "UART.h"          // Includes uart init functions
#include "UART1_comm.h"    // Includes uart1 communication functions
#include "SPI_comm.h"      // Include SPI communication functions

// Declare parse_uart1_packet prototype
void parse_uart1_packet(void);

// Define maximum buffer size for dynamic record length
#define MAX_RECORD_LENGTH 1000
volatile uint8_t buffer_a[MAX_RECORD_LENGTH]; // triple buffer A
volatile uint8_t buffer_b[MAX_RECORD_LENGTH]; // triple buffer B
volatile uint8_t buffer_c[MAX_RECORD_LENGTH]; // triple buffer C
volatile uint8_t *active_buffer = buffer_a;   // buffer we write into
volatile uint8_t *send_buffer = buffer_b;     // buffer we send from
volatile uint8_t *standby_buffer = buffer_c;  // next available buffer
volatile bool buffer_in_use = false;          // indicates if buffer is locked for transmission
volatile uint16_t current_timer1_top = 200;   // ADC sampling rate control (OCR1A value)
volatile uint16_t record_length = 100;        // number of samples per transmission

// ADC control flags
volatile uint16_t sample_index = 0; // current sample index into active buffer
volatile bool buffer_ready = false; // signals that a full buffer is ready to send

// BTN/SW state
volatile uint8_t btn = 0;
volatile uint8_t sw = 0;
volatile uint8_t run_stress_test_flag = 0; // triggered by LabVIEW START (BTN3)

// Enumeration for program states
enum states
{
    state_init,
    state_Run,
    state_Stop,
    state_SPITest
};
static enum states state = state_init;

// Interrupt Service Routine (ISR) for TIMER1 Compare Match B (see ADC.c for more info)
ISR(TIMER1_COMPB_vect)
{
    if (sample_index < record_length)
    {
        active_buffer[sample_index++] = ADCH;
    }
    else if (!buffer_in_use)
    {
        cli();
        buffer_ready = true;
        buffer_in_use = true;

        // rotate buffers: standby → send → active
        uint8_t *temp = (uint8_t *)standby_buffer;
        standby_buffer = send_buffer;
        send_buffer = active_buffer;
        active_buffer = temp;

        sample_index = 0;
        sei();
    }
    // if buffer is still in use, skip storing until main clears it
}

int main(void)
{
    while (1)
    {
        parse_uart1_packet(); // check for UART1 commands from LabVIEW

        switch (state)
        {
        case state_init:

            init_ADC_kanal0();                           // configure ADC0 with auto-trigger via Timer1
            init_timer1(current_timer1_top);             // configure Timer1 for ADC sampling
            master_init();                               // initialize SPI as master
            uart_init(16);                               // init UART0 (115200 baud)
            uart1_init(16);                              // init UART1 (115200 baud, for LabVIEW)
            uart_send_string("System initialized.\r\n"); // confirm system boot
            DDRD |= (1 << PD7);                          // configure PD7 as output (FPGA reset)
            PORTD &= ~(1 << PD7);                        // ensure reset line is low

            sei();             // enable global interrupts
            state = state_Run; // move to Run state
            break;

        case state_Run:

            if (run_stress_test_flag)
            {
                run_stress_test_flag = 0;
                state = state_SPITest;
            }

            if (buffer_ready)
            {
                // Disable interrupts while accessing shared buffers, to prevent them from being modified during transmission
                // this is necessary to ensure data integrity as the ISR may write to the buffer while we are sending it
                cli();
                buffer_ready = false;
                buffer_in_use = false;
                sei();

                // send data to LabVIEW
                send_oscilloscope_packet((uint8_t *)send_buffer, record_length);
                _delay_ms(9); // wait for UART to complete before sending debug text

                uart_send_string("\rSample: ");
                char buf[16];
                sprintf(buf, "%02X      ", send_buffer[0]);
                uart_send_string(buf);
            }

            if (run_stop_flag)
            {
                state = state_Stop;
            }
            break;

        case state_Stop:
            if (!(run_stop_flag))
            {
                state = state_Run; // resume sampling when unpaused
            }
            break;

        case state_SPITest:
            spi_stress_test_10000_packets(); // run SPI communication stress test
            state = state_Run;
            break;

        default:
            break;
        }
    }
}

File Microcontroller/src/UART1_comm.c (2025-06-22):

// ## Program developed by Mads Rodulph and Sigurd Hestbech Christiansen ##
// ## Last edited: 21-6-2025 ##
// ## This file contains UART1 communication functions ##

#include <avr/io.h>
#include <avr/interrupt.h>
#include <string.h>
#include <util/delay.h>
#include <stdio.h>
#include "UART1_comm.h"
#include "UART.h"
#include "ADC.h"
#include "SPI.h"
#include "SPI_comm.h"

#define MAX_RECORD_LENGTH 1000               // max samples allowed per oscilloscope packet
extern volatile uint16_t record_length;      // current active record length
extern volatile uint16_t current_timer1_top; // timer TOP value for sampling rate
static uint8_t selected_param = 0;           // user-selected parameter: 0 = shape, 1 = amplitude, 2 = frequency

volatile uint8_t shape = 0;         // waveform shape: 0-3 (const, square, saw, sine)
volatile uint8_t amplitude = 128;   // waveform amplitude (0-255)
volatile uint8_t frequency = 100;   // waveform frequency (custom encoded)
volatile uint8_t run_stop_flag = 0; // flag toggled by BTN2 (pause/resume)
float sample_rate = 0;              // calculated sample rate in Hz

#define UART1_RX_BUFFER_SIZE 128
volatile uint8_t uart1_rx_buffer[UART1_RX_BUFFER_SIZE]; // circular RX buffer
volatile uint8_t uart1_rx_index = 0;                    // current write index in RX buffer
volatile uint8_t uart1_packet_ready = 0;                // set when complete packet is received

// UART1 RX interrupt — assembles bytes into packet buffer and checks length field
ISR(USART1_RX_vect)
{
    uint8_t byte = UDR1;

    if (uart1_rx_index < UART1_RX_BUFFER_SIZE)
    {
        uart1_rx_buffer[uart1_rx_index++] = byte;

        // once header is complete, check if full packet has arrived
        if (uart1_rx_index >= 5)
        {
            uint16_t length = (uart1_rx_buffer[2] << 8) | uart1_rx_buffer[3];
            if (uart1_rx_index == length)
                uart1_packet_ready = 1; // entire packet received
        }
    }
    else
    {
        uart1_rx_index = 0; // reset buffer if overflow occurs
    }
}

// Send a full oscilloscope data packet to LabVIEW
void send_oscilloscope_packet(uint8_t *samples, uint16_t length)
{
    TIMSK1 &= ~(1 << OCIE1B); // Disable Timer1 Compare Match B interrupt, with the purpose of disableing ADC auto-trigger

    uart1_send(0x55); // sync byte 1
    uart1_send(0xAA); // sync byte 2

    uint16_t payload_length = 2 + 2 + 1 + length + 2; // full packet size including header and checksum
    uart1_send((payload_length >> 8) & 0xFF);         // length high byte
    uart1_send(payload_length & 0xFF);                // length low byte
    uart1_send(0x02);                                 // packet type: OSCILLOSCOPE (0x02)

    for (uint16_t i = 0; i < length; i++)
        uart1_send(samples[i]); // send all sample data (1 byte each)

    uart1_send(0x00); // checksum byte 1
    uart1_send(0x00); // checksum byte 2

    while (!(UCSR1A & (1 << TXC1)))
        ;                  // wait for final byte to be fully shifted out
    UCSR1A |= (1 << TXC1); // clear transmit complete flag

    TIMSK1 |= (1 << OCIE1B); // re-enable ADC auto-trigger
}

// Send current generator configuration back to LabVIEW
void send_generator_packet(uint8_t active, uint8_t shape, uint8_t ampl, uint8_t freq)
{
    uart1_send(0x55); // sync
    uart1_send(0xAA);
    uart1_send(0x00);
    uart1_send(0x0B);   // total length = 11 bytes
    uart1_send(0x01);   // packet type: GENERATOR (0x01)
    uart1_send(active); // LED select (0 = shape, 1 = amp, 2 = freq)
    uart1_send(shape);  // waveform shape
    uart1_send(ampl);   // amplitude
    uart1_send(freq);   // frequency
    uart1_send(0x00);   // checksum
    uart1_send(0x00);
}

// Parse incoming LabVIEW packet and respond accordingly
void parse_uart1_packet()
{
    if (!uart1_packet_ready)
        return;
    uart1_packet_ready = 0;

    if (uart1_rx_buffer[0] != 0x55 || uart1_rx_buffer[1] != 0xAA)
    {
        uart1_rx_index = 0; // invalid sync header
        return;
    }

    uint16_t length = (uart1_rx_buffer[2] << 8) | uart1_rx_buffer[3];
    if (length > UART1_RX_BUFFER_SIZE)
    {
        uart1_rx_index = 0; // reject oversized packet
        return;
    }

    uint8_t type = uart1_rx_buffer[4];

    switch (type)
    {
    case 0x01:
    {
        uint8_t btn = uart1_rx_buffer[5];
        uint8_t sw = uart1_rx_buffer[6];

        char msg[64];
        sprintf(msg, "BTN: %d, SW: %d\r\n", btn, sw);
        uart_send_string(msg);

        switch (btn)
        {
        case 0x00: // SEND pressed
            uart_send_string("BTN0 pressed: Send current values\r\n");
            if (selected_param == 0 && sw <= 4)
                shape = sw;
            else if (selected_param == 1 && sw <= 255)
                amplitude = sw;
            else if (selected_param == 2 && sw <= 255)
                frequency = sw;
            else
                uart_send_string("error: invalid parameter value\r\n");

            transmit_signalgenerator_data(amplitude, frequency, shape);
            uart_send_string("Current values sent to FPGA\r\n");
            break;

        case 0x01: // PARAM SELECT pressed
            selected_param = (selected_param + 1) % 3;
            uart_send_string("BTN1 pressed: Cycle parameter\r\n");
            break;

        case 0x02: // RUN/PAUSE pressed
            run_stop_flag = !run_stop_flag;
            uart_send_string(run_stop_flag ? "Paused\r\n" : "Running\r\n");
            break;

        case 0x03: // RESET pressed
            uart_send_string("BTN3 pressed: Reset\r\n");
            PORTD |= (1 << PD7);
            _delay_ms(10);
            PORTD &= ~(1 << PD7); // pulse reset to FPGA
            selected_param = 0;
            shape = 0;
            amplitude = 128;
            frequency = 1;
            transmit_signalgenerator_data(amplitude, frequency, shape);
            uart_send_string("Reset values sent to FPGA\r\n");
            break;

        default:
            uart_send_string("Unknown BTN value\r\n");
            break;
        }

        send_generator_packet(selected_param, shape, amplitude, frequency);
        break;
    }

    case 0x02:
    {
        uint16_t record_len = (uart1_rx_buffer[7] << 8) | uart1_rx_buffer[8];
        if (record_len > 0 && record_len <= MAX_RECORD_LENGTH)
        {
            record_length = record_len;
            // set optimal sample rate based on record length
            sample_rate = ((11520.0f * record_length) / (7.0f + record_length)) * 0.95f; // calculate sample rate
            current_timer1_top = F_CPU / (8.0f * sample_rate);
            init_timer1(current_timer1_top); // reconfigure Timer1 for new sample rate
        }

        char msg[64];
        uart_send_string("\r\n=== Oscilloscope Configuration ===\r\n");

        snprintf(msg, sizeof(msg), "Record Length: %u samples\r\n", record_length);
        uart_send_string(msg);
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

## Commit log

2025-06-04 Signalgenerator, work in progress
    [SigGenTop_pad.csv]
2025-06-04 Signal Generator Works
    [SigGenTop_pad.csv]
2025-06-04 Added uart.c and uart.h
2025-06-04 fixed uart files
2025-06-05 Moved SignalGenerator into fpga folder
    [SigGenTop_pad.csv]
2025-06-05 SPI indstilles til at sende 170
2025-06-05 forbedrede kommenta i SPI.c
2025-06-05 SPI configured correctly
2025-06-06 små retelser i SPI.c
2025-06-06 komentarer i SPI.c
2025-06-06 Temp branch to save SPI_test FPGA
    [Skifte_reg_til_Parallel_pad.csv, TB_isim_beh.exe_main.nt64.obj, a_3580701064_3212880686.nt64.obj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]
2025-06-06 opdateret til main.c uart.c
2025-06-06 små forbedringer i main.c og uart.c
2025-06-06 Top modul og statemachine 1.0
    [TB_isim_beh.exe_main.nt64.obj, a_3580701064_3212880686.nt64.obj]
2025-06-06 Set up Uart com both ways, having chksum & sync errors
    [ADC.c, main.c, uart.c]
2025-06-07 Fixed Uart protocol, but still chksum and sync eroors, work in progress
    [ADC.c, main.c, uart.c]
2025-06-09 Fixed FSM + TB - Mangler SigEN fix
    [TB_TOP34444_isim_beh.exe_main.nt64.obj, TB_isim_beh.exe_main.nt64.obj, a_0800547850_3212880686.nt64.obj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]
2025-06-10 komenterede sidetal tilføjet til ADC.c og uart.c
2025-06-10 Parsed btn press works, need to work on spi
2025-06-10 Enable V1
    [TB_TOP34444_isim_beh.exe_main.nt64.obj, a_0800547850_3212880686.nt64.obj, a_1808905686_2372691052.nt64.obj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]
2025-06-11 fixed generator buttons interfering with oscilloscope send
    [uart.c]
2025-06-11 Tilstandsmakine virker, TB virker
    [TB_TOP34444_isim_beh.exe_main.nt64.obj, a_0440160552_3212880686.nt64.obj, a_0800547850_3212880686.nt64.obj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]
2025-06-11 SigEN virker og alt er lækkert
    [TB_TOP34444_isim_beh.exe_main.nt64.obj, a_1808905686_2372691052.nt64.obj, a_2629034234_3212880686.nt64.obj]
2025-06-11 added LTspice folder for filter
2025-06-12 Samlet Program
    [SigGenTop_pad.csv]
2025-06-12 Added kicad folder for filter design
    [FilterDesign.kicad_pcb, FilterDesign.kicad_sch]
2025-06-12 Register Magi
    [SigGenTop_pad.csv]
2025-06-12 maple document til udregning af filter
2025-06-12 mads du har flotte blå øjne
    [SigGenTop_pad.csv]
2025-06-12 Der er et Problem vi ikke ved hvad er
    [FULL_BENCH_isim_beh.exe_main.nt64.obj, ProtokolBlok_isim_beh.exe_main.nt64.obj, SigGenTop_pad.csv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]
2025-06-13 signalgenerator og PWM virker
    [FULL_BENCH_isim_beh.exe_main.nt64.obj, SigGenTop_pad.csv, a_2629034234_3212880686.nt64.obj]
2025-06-13 started working on filter design in Kicad
    [FilterDesign.kicad_sch]
2025-06-13 7Seg virker, resten er gået i stykker:(
    [SigGenTop_pad.csv]
2025-06-13 Worked on filter simulation in KiCad
    [FilterDesign.kicad_sch]
2025-06-14 Added new README.md and worked on filter
    [FilterDesign.kicad_sch]
2025-06-14 Working on Active filter
    [Active_Filter.kicad_sch, FilterDesign.kicad_sch, Passive_filter.kicad_sch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]
2025-06-16 7 seg virker
    [FULL_BENCH_isim_beh.exe_main.nt64.obj, SigGenTop_isim_beh.exe_main.nt64.obj, SigGenTop_pad.csv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]
2025-06-16 Sallen-key topology low-pass filter tilføjet i kicad
    [FilterDesign.kicad_sch, Passive_filter.kicad_sch, Sallen-key topology low-pass.kicad_sch]
2025-06-16 spi baud-rate sat til 500k
2025-06-16 Opdateret run signal
    [SigGenTop_pad.csv]
2025-06-16 More kicad stuff
2025-06-16 checksumEN Tilstand tilføjet
    [SigGenTop_pad.csv]
2025-06-16 KICAD SIM IS HARD
    [AktivtFilterSim.kicad_pcb, AktivtFilterSim.kicad_sch, TLV2372.DSN]
2025-06-16 øget pwm frekvens, ikke testet
    [SigGenTop_pad.csv]
2025-06-16 Added Kicad to .gitignore
2025-06-17 ADC now uses 3.3 as AREF :-)
2025-06-17 Test der ikke virker og jeg græder og tuder waaaah
    [SigGenTop_pad.csv]
2025-06-17 spi stresstest & Kicad stuff
    [AktivtFilterSim.kicad_sch, Comparator.kicad_pcb, Comparator.kicad_sch]
2025-06-18 beregninger for 4'ordens filter uden gain
2025-06-18 Tilføjet stresstest som virker
    [FULL_BENCH_isim_beh.exe_main.nt64.obj, SigGenTop_isim_beh.exe_main.nt64.obj, SigGenTop_pad.csv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]
2025-06-18 SPI StressTest implemented
2025-06-19 Alt Virker!
    [SigGenTop_pad.csv]
2025-06-19 Staged changes to be able to merge to main
    [AktivtFilterSim.kicad_sch, Comparator.kicad_sch, Sallen-key topology low-pass.kicad_sch]
2025-06-20 added .bit file, and fixed syntax
    [SigGenTop_pad.csv]
2025-06-20 Added reset signal from MCU
    [SigGenTop_pad.csv]
2025-06-20 Added reset signal to fpga from labview reset
    [main.c, uart.c]
2025-06-20 fixed reset and stresstest complications
    [SPI.c]
2025-06-20 ny beregning af sample rate
2025-06-20 små ting i uart.c
2025-06-21 Implemented new max samplerate, and fixed alot of issues
    [main.c, uart.c]
2025-06-21 finpuset coden og opdelt comm fra spi og uart i hver sin src fil
2025-06-22 Reset er nu gennem LabVIEW og DataReady fikset
    [FULL_BENCH_isim_beh.exe_main.nt64.obj, SigGenTop_pad.csv, a_0440160552_3212880686.nt64.obj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]
2025-06-23 Created final filter schematic
    [FinalFilter.kicad_pcb, FinalFilter.kicad_sch]
